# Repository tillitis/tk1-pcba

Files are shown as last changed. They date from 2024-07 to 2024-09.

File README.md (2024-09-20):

# TK1 PCBA

This repository contains the PCB design and manufacturing files for
the flexible Open Source security key, TKey (TK1).

This is part of a larger project that includes firmware and FPGA
designs, which are housed at
[tillitis-key1](https://github.com/tillitis/tillitis-key1).

For more general information about the TKey see,
- [www.tillitis.se](https://tillitis.se)
- [shop.tillitis.se](https://shop.tillitis.se)
- [TKey Developer Handbook](https://dev.tillitis.se/)

## Repository Contents
- KiCad project files for
    - tk1, under hw
    - mta1-usb-v1, under prototypes
    - mta1-usb-dev, under prototypes
- Manufacturing outputs (Gerber files, BOM, etc.), under [Github
  releases](https://github.com/tillitis/tk1-pcba/releases)
- Libraries, under hw/lib

The earlier version of TK1, such as the `mta1-usb-v1` and
`mta1-usb-dev`, that can be found under `prototypes/` are kept for
historical reasons. TK1 is the only version that is maintained and
developed.

## Getting started
1. Clone this repository:
2. Open the project file (`hw/tk1.kicad_pro`) in KiCad.

alternatively download a release to get the generated output (Gerber,
schematics etc.) to be viewed in your preferred tool.

## KiCad and tools
The project is built using KiCad version 7. Production files are built
in CI using KiBot, see the Makefile for exact version.

The KiBot flow can be run locally using the Make target

```
make run-kibot
```

the prerequisites are `Podman`. `Docker` can also be used, see the
Makefile for details.

## License
Unless otherwise noted, this project is licensed under CERN Open
Hardware License Version 2 - Strongly Reciprocal, see full license
under [LICENSE.txt](/LICENSE.txt).
```
Copyright Tillitis AB 2022-2024.

This source describes Open Hardware and is licensed under the CERN-OHL-S v2.

You may redistribute and modify this source and make products using it under
the terms of the CERN-OHL-S v2 (https://ohwr.org/cern_ohl_s_v2.txt).

This source is distributed WITHOUT ANY EXPRESS OR IMPLIED WARRANTY,
INCLUDING OF MERCHANTABILITY, SATISFACTORY QUALITY AND FITNESS FOR A
PARTICULAR PURPOSE. Please see the CERN-OHL-S v2 for applicable conditions.

Source location: https://github.com/tillitis/tk1-pcba

As per CERN-OHL-S v2 section 4, should You produce hardware based on this
source, You must where practicable maintain the Source Location visible
on the external case of the product or its packaging, and in its
documentation, even after modification.
```

The [CERN-OHL-S user guide](/User-guide-CERN-OHL-S.txt) is included to
make it easier to follow the license, both as a Licensor or a Licensee.

## History
This repo was created by filtering out relevant commits and files from
the [tillitis/tillits-key1](https://github.com/tillitis/tillitis-key1)
repo.

The filtering removed all files and commits that weren't related to
the tk1 hardware. This was done using
[git-filter-repo](https://github.com/newren/git-filter-repo).

To replicate the results up until commit `6c7629c` in this repo,
checkout commit `354aecb` in `tillitis/tillitis-key1` and run
`git-filter-repo --path hw/boards/mta1-library --path
hw/boards/mta1-usb-dev --path hw/boards/mta1-usb-v1 --path
hw/boards/tk1`.

All filtered commits have intact date, author, and code. Some
unrelated files are removed from some commits, but the commit messages
are left unchanged. Commit sha, tags and signatures are new. For
complete history, please see tillitis/tillitis-key1 from commit
`354aecb` and earlier.

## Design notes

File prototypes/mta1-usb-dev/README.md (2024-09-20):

# mta1-usb-dev

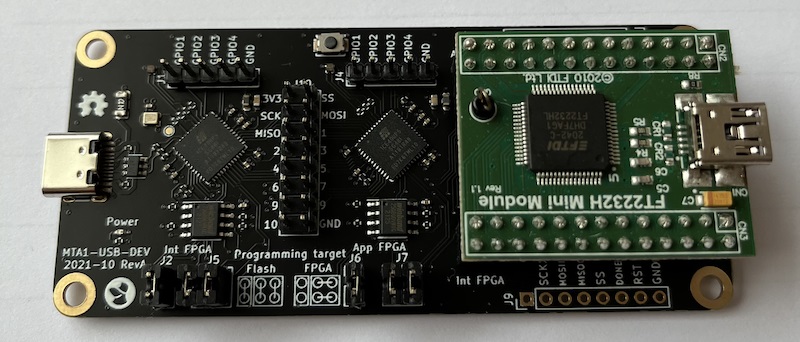
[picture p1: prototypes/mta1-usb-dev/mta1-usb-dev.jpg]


This is the original TKey design, intended as a development platform.
It is a larger PCB, that connects to a PC via a USB C cable.

Main features:
- 2 ICE40 FPGAs.

- The first ICE40 (Interface FPGA) is connected to a USB C plug, and
is loaded with a gateware that contains a soft USB device. This
gateware acts as an USB-to-GPIO interface to the second ICE40.

- The second ICE40 (application FPGA) is loaded with a RISC-V soft
core containing the security firmware. User applications are run on
this gateware.

- The second ICE40 also has an input button for user presenence
detection.

- An FTDI module is included for programming both the Application and
Interface FPGAs.

- Both ICE40s can be configured to boot from included SPI flash
memories, NVCM, or be live programmed from the FTDI module.

- All GPIO lines between the two FPGAs, as well as all programming
signals, are exposed on 0.1" headers for probing.

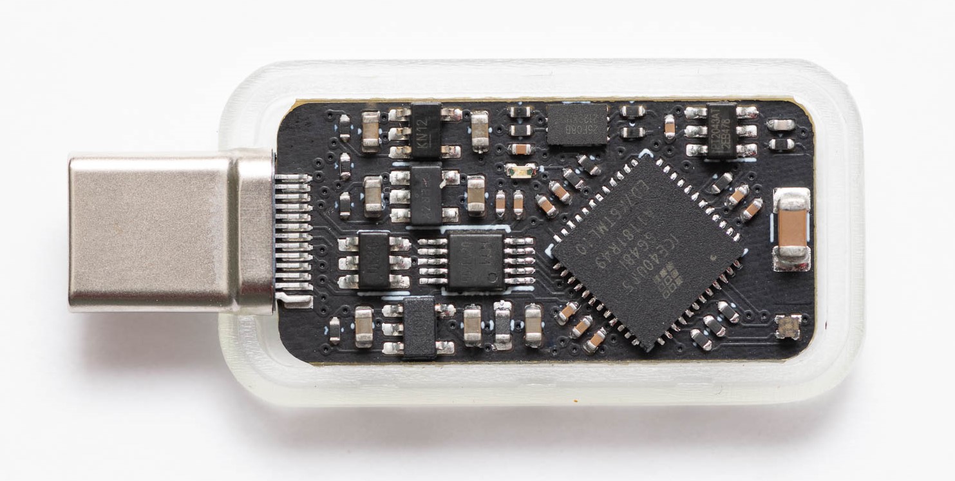
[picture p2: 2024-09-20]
prototypes/mta1-usb-v1/mta1-usb-v1.jpg

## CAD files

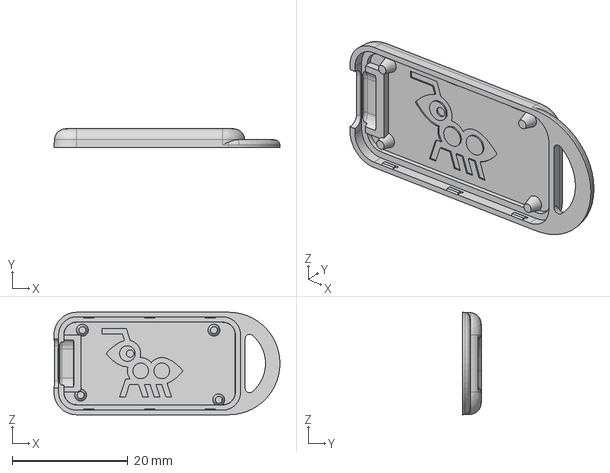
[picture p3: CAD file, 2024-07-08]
hw/case_plastic/3D_printed/case_top_revc.step
39.0 x 3.20 x 17.7 mm

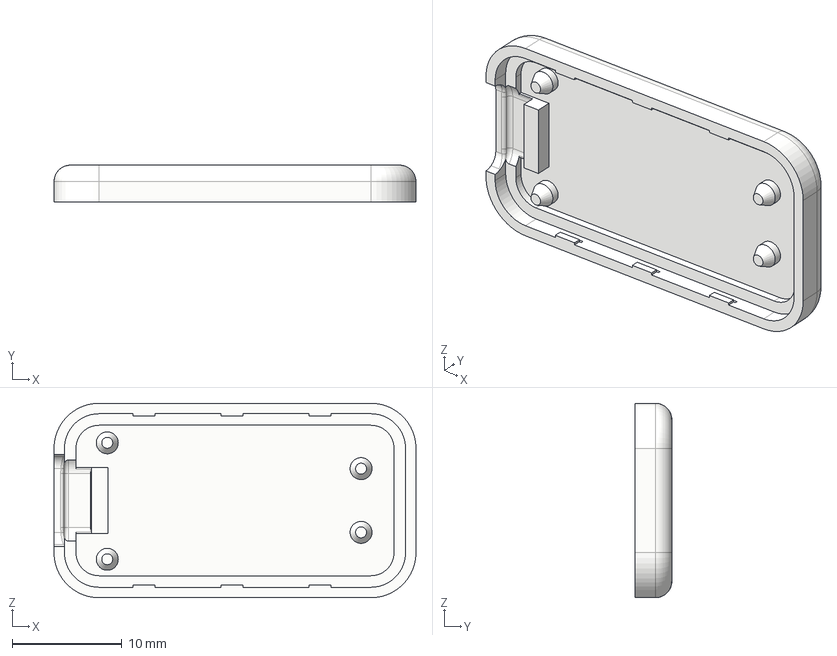
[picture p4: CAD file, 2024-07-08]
prototypes/mta1-usb-v1/case_plastic/2022-08-22 case production top.step
33.0 x 3.35 x 17.7 mm

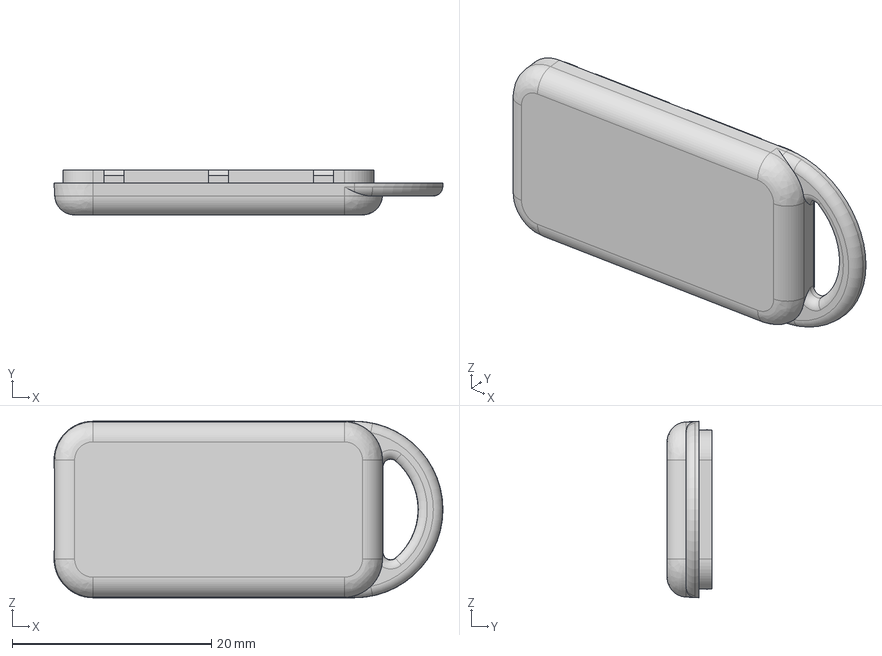
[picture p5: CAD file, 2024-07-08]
hw/case_plastic/3D_printed/case_bottom_revc.step
39.0 x 4.50 x 17.7 mm

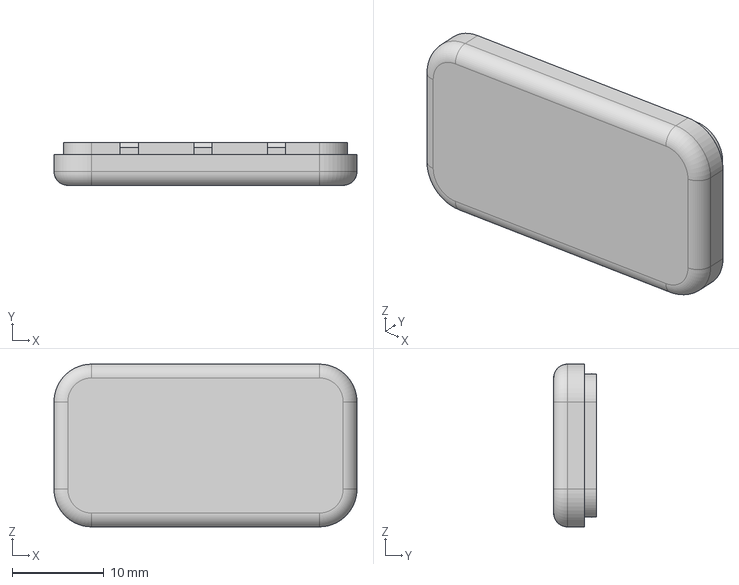
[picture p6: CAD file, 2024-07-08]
prototypes/mta1-usb-v1/case_plastic/2022-08-22 case production bottom.step
33.0 x 4.65 x 17.7 mm

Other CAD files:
prototypes/mta1-usb-v1/case_plastic/2022-08-22 case v3.f3z

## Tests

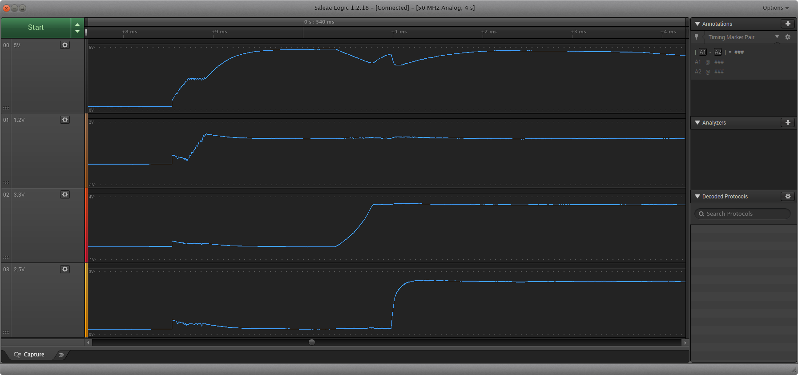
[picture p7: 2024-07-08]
prototypes/mta1-usb-dev/test/voltage_rails_test.png

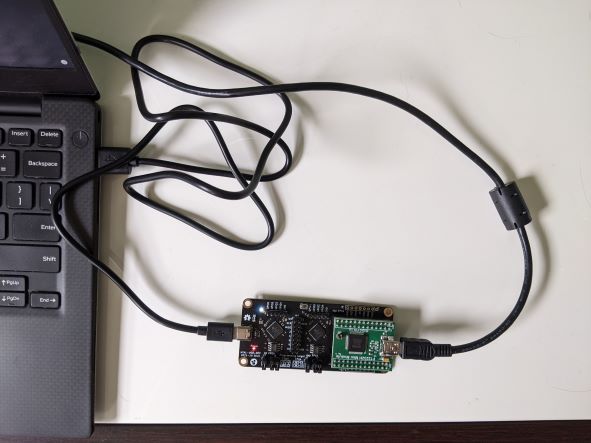
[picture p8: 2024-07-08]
prototypes/mta1-usb-dev/test/usb_test_setup.jpg

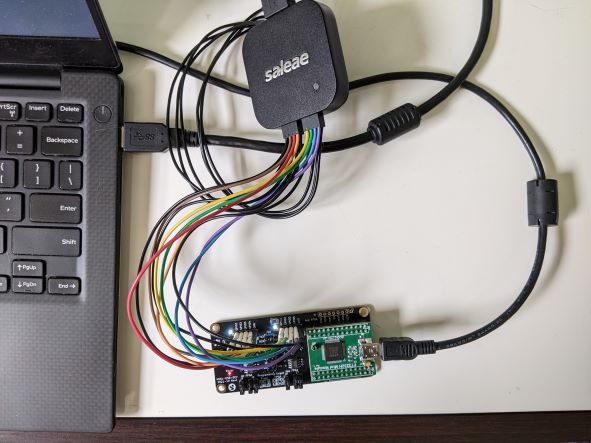
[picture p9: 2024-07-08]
prototypes/mta1-usb-dev/test/gpio_test_setup.jpg

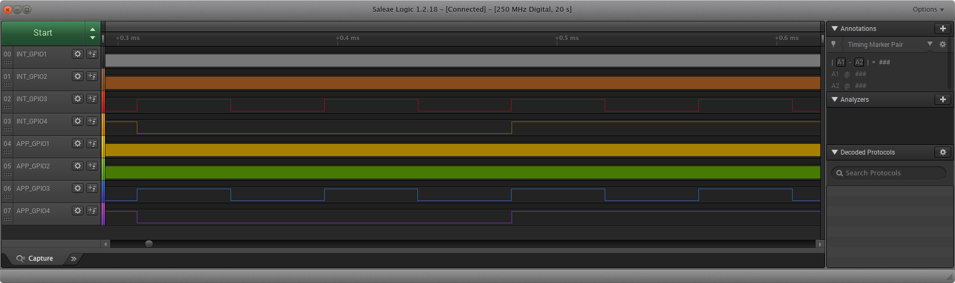
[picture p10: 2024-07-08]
prototypes/mta1-usb-dev/test/gpio_test.png

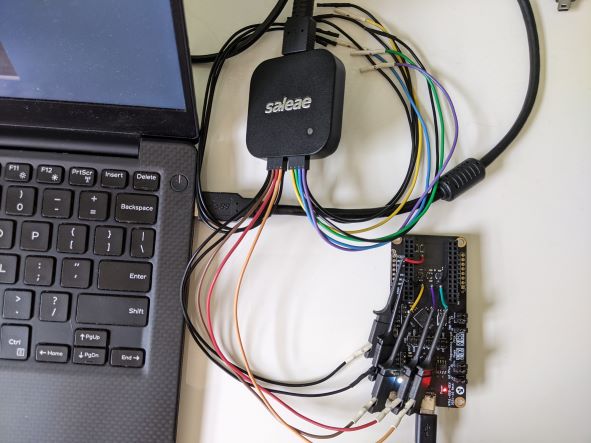
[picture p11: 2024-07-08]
prototypes/mta1-usb-dev/test/voltage_rail_test_setup.jpg

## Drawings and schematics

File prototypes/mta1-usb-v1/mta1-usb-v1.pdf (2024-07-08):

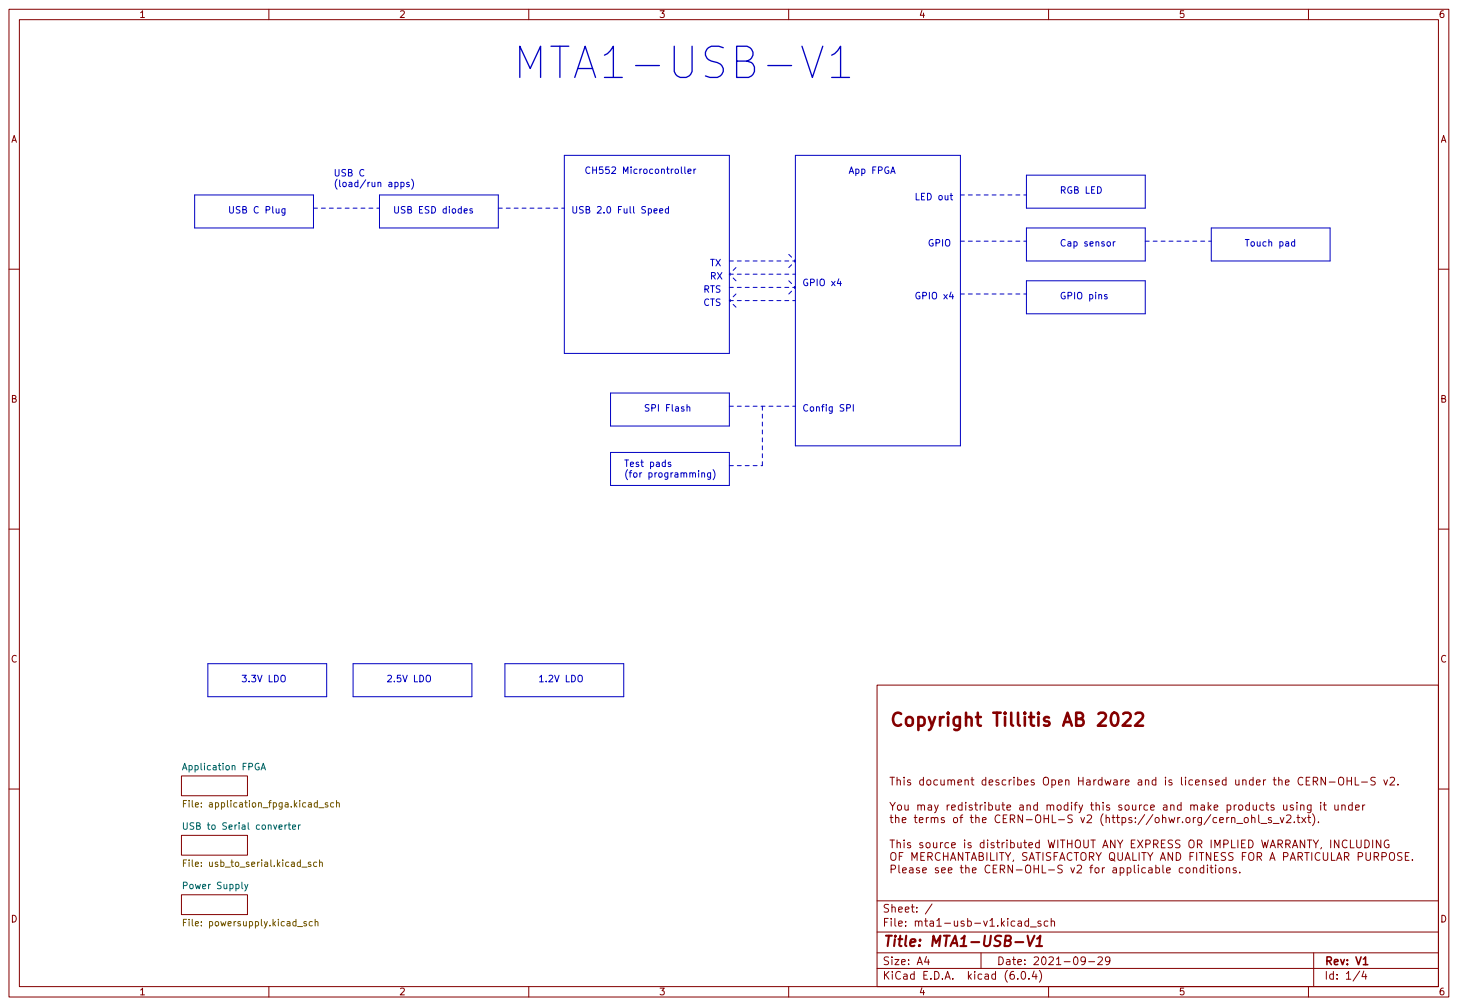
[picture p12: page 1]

Cap sensor USB ESD diodes USB C
(load/run apps)

File: application_fpga.kicad_sch USB to Serial converter File: usb_to_serial.kicad_sch Power Supply

File: mta1-usb-v1.kicad_sch Sheet: / This document describes Open Hardware and is licensed under the CERN-OHL-S v2.

You may redistribute and modify this source and make products using it under

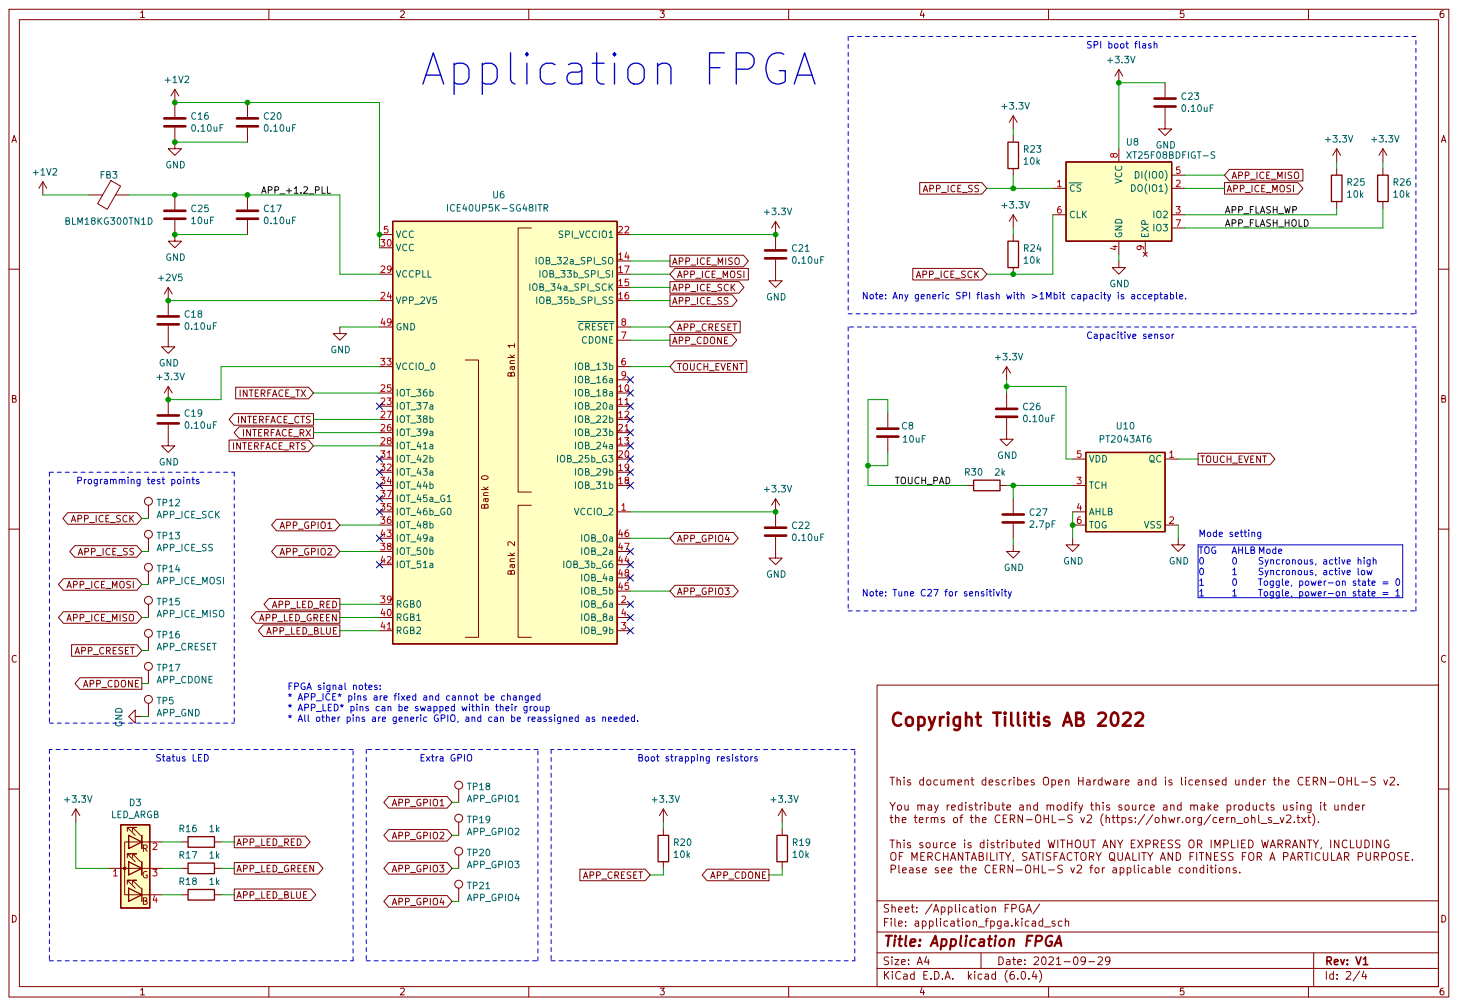
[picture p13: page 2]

1 Note: Any generic SPI flash with >1Mbit capacity is acceptable. SPI boot flash

Toggle, power-on state = 1 AHLB
Syncronous, active low
Toggle, power-on state = 0

Note: Tune C27 for sensitivity

FPGA signal notes:
* APP_ICE* pins are fixed and cannot be changed
* APP_LED* pins can be swapped within their group
* All other pins are generic GPIO, and can be reassigned as needed.

This document describes Open Hardware and is licensed under the CERN-OHL-S v2.

You may redistribute and modify this source and make products using it under

Sheet: /Application FPGA/
File: application_fpga.kicad_sch
Id: 2/4 Title: Application FPGA

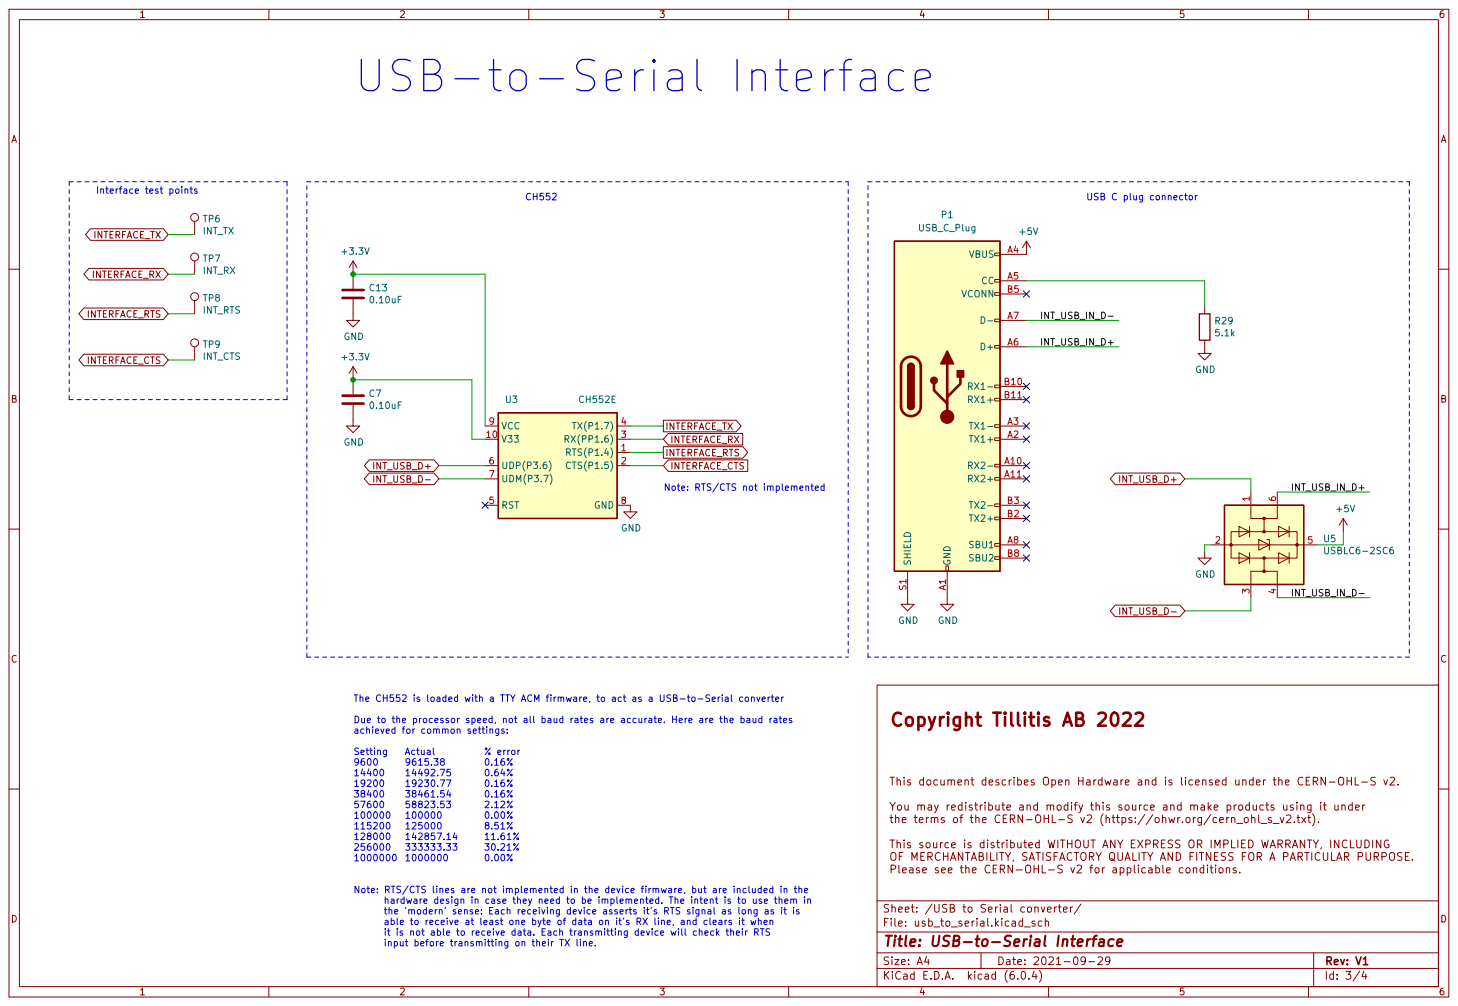
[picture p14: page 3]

USB-to-Serial Interface

INT_USB_IN_D- The CH552 is loaded with a TTY ACM firmware, to act as a USB-to-Serial converter Due to the processor speed, not all baud rates are accurate. Here are the baud rates

achieved for common settings:

File: usb_to_serial.kicad_sch Sheet: /USB to Serial converter/ This document describes Open Hardware and is licensed under the CERN-OHL-S v2.

You may redistribute and modify this source and make products using it under

Note: RTS/CTS lines are not implemented in the device firmware, but are included in the
hardware design in case they need to be implemented. The intent is to use them in
the 'modern' sense: Each receiving device asserts it's RTS signal as long as it is
able to receive at least one byte of data on it's RX line, and clears it when
it is not able to receive data. Each transmitting device will check their RTS
input before transmitting on their TX line.

Id: 3/4 Title: USB-to-Serial Interface

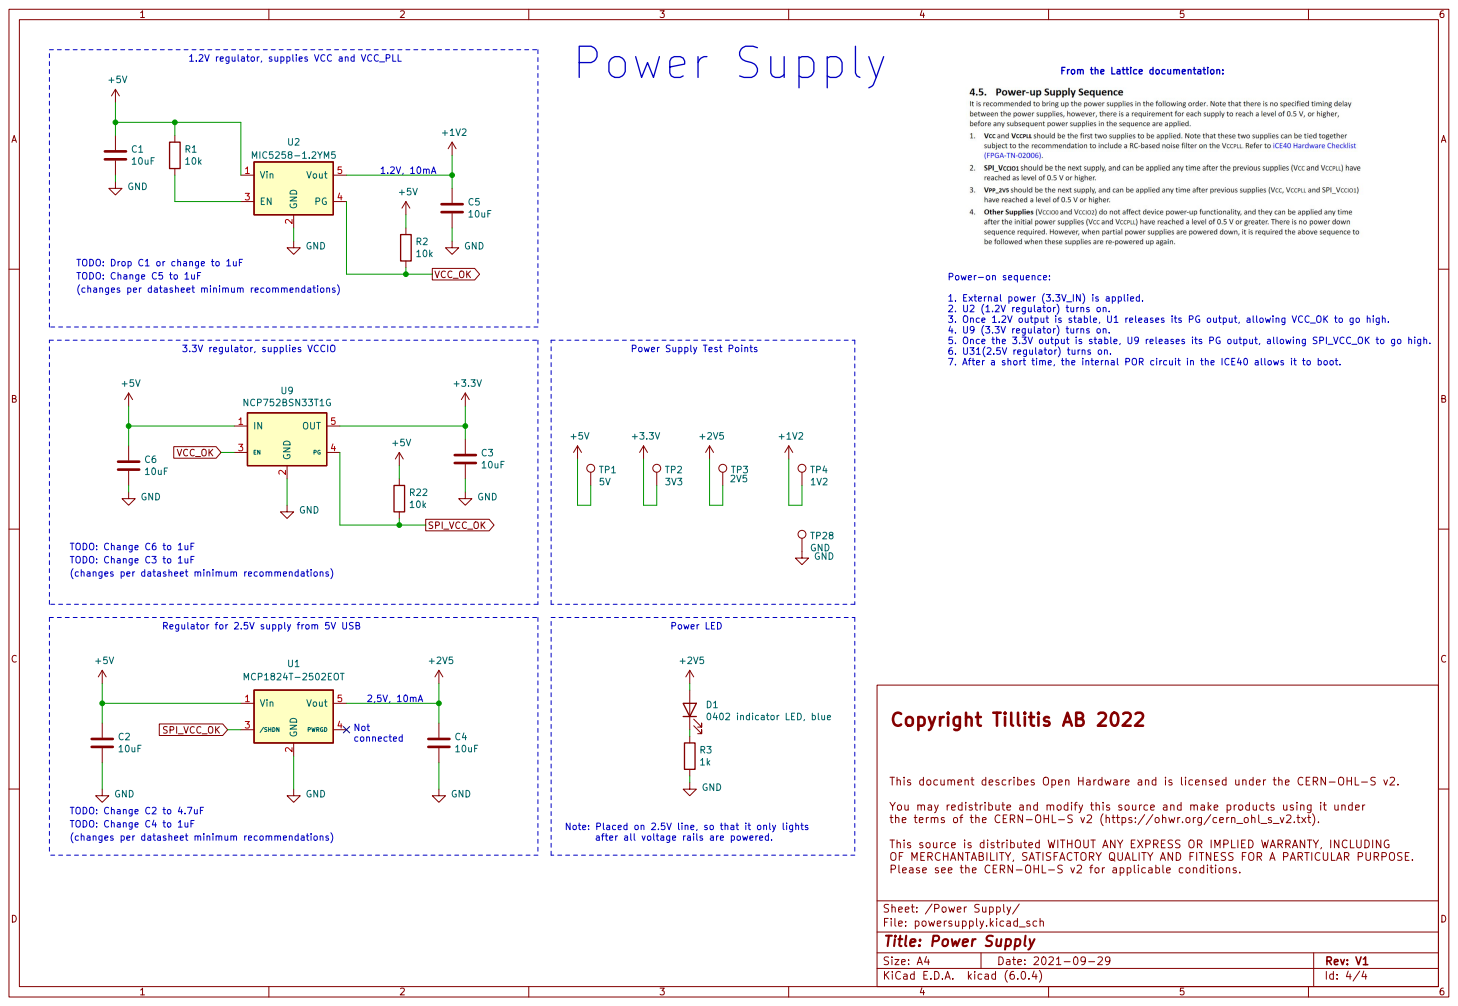
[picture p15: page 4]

1.2V regulator, supplies VCC and VCC_PLL

TODO: Drop C1 or change to 1uF
TODO: Change C5 to 1uF
(changes per datasheet minimum recommendations)

1. External power (3.3V_IN) is applied.
2. U2 (1.2V regulator) turns on.
3. Once 1.2V output is stable, U1 releases its PG output, allowing VCC_OK to go high.
4. U9 (3.3V regulator) turns on.
5. Once the 3.3V output is stable, U9 releases its PG output, allowing SPI_VCC_OK to go high.

TODO: Change C6 to 1uF
TODO: Change C3 to 1uF

2,5V, 10mA Regulator for 2.5V supply from 5V USB

TODO: Change C2 to 4.7uF
TODO: Change C4 to 1uF

Note: Placed on 2.5V line, so that it only lights
after all voltage rails are powered.

This document describes Open Hardware and is licensed under the CERN-OHL-S v2.

You may redistribute and modify this source and make products using it under

Sheet: /Power Supply/
File: powersupply.kicad_sch
Id: 4/4 Title: Power Supply

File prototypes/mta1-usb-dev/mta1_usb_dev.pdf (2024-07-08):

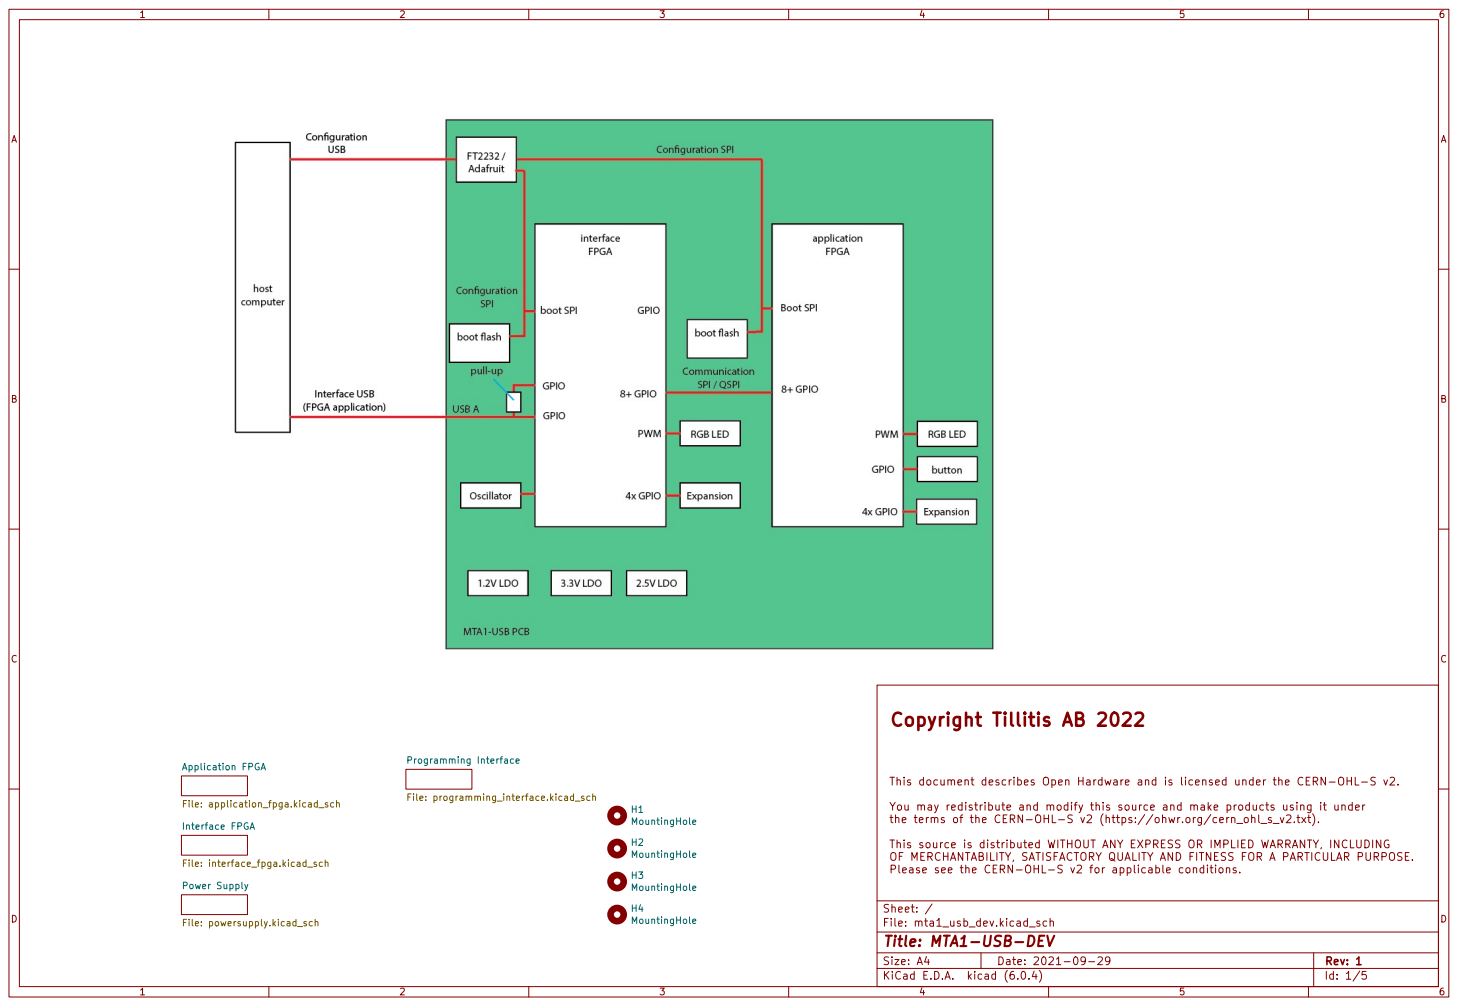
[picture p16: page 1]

File: mta1_usb_dev.kicad_sch Sheet: / This document describes Open Hardware and is licensed under the CERN-OHL-S v2.

You may redistribute and modify this source and make products using it under

Id: 1/5 Title: MTA1-USB-DEV

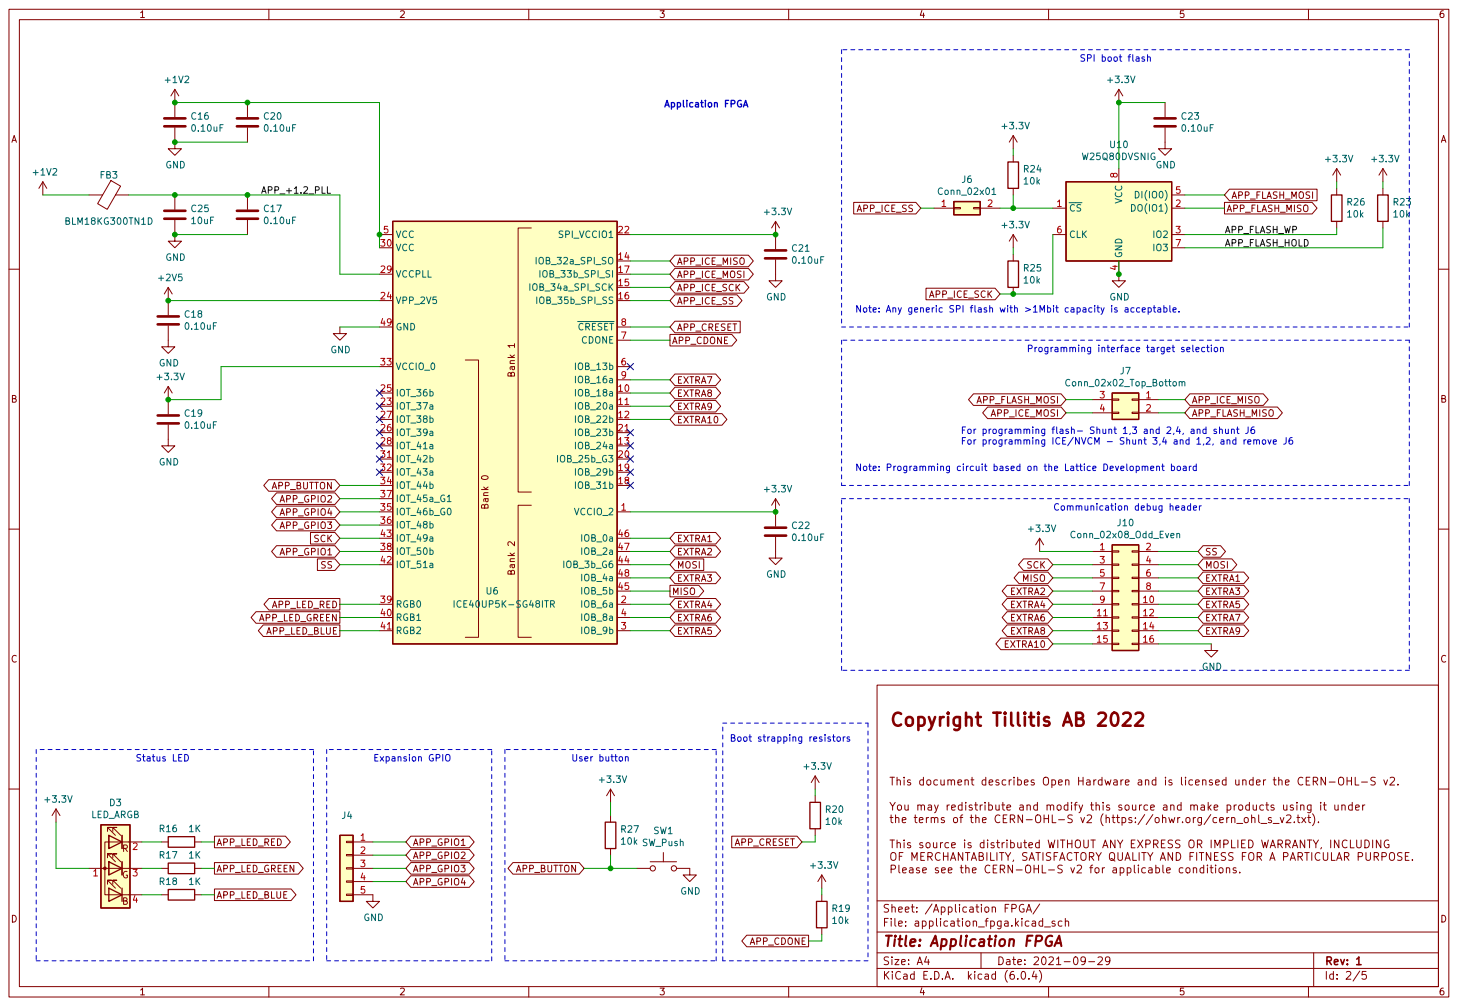
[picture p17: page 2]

Programming interface target selection SPI boot flash Application FPGA

Note: Any generic SPI flash with >1Mbit capacity is acceptable.

For programming ICE/NVCM - Shunt 3,4 and 1,2, and remove J6

Note: Programming circuit based on the Lattice Development board

Boot strapping resistors Status LED

This document describes Open Hardware and is licensed under the CERN-OHL-S v2.

You may redistribute and modify this source and make products using it under

Sheet: /Application FPGA/
File: application_fpga.kicad_sch
Id: 2/5 Title: Application FPGA

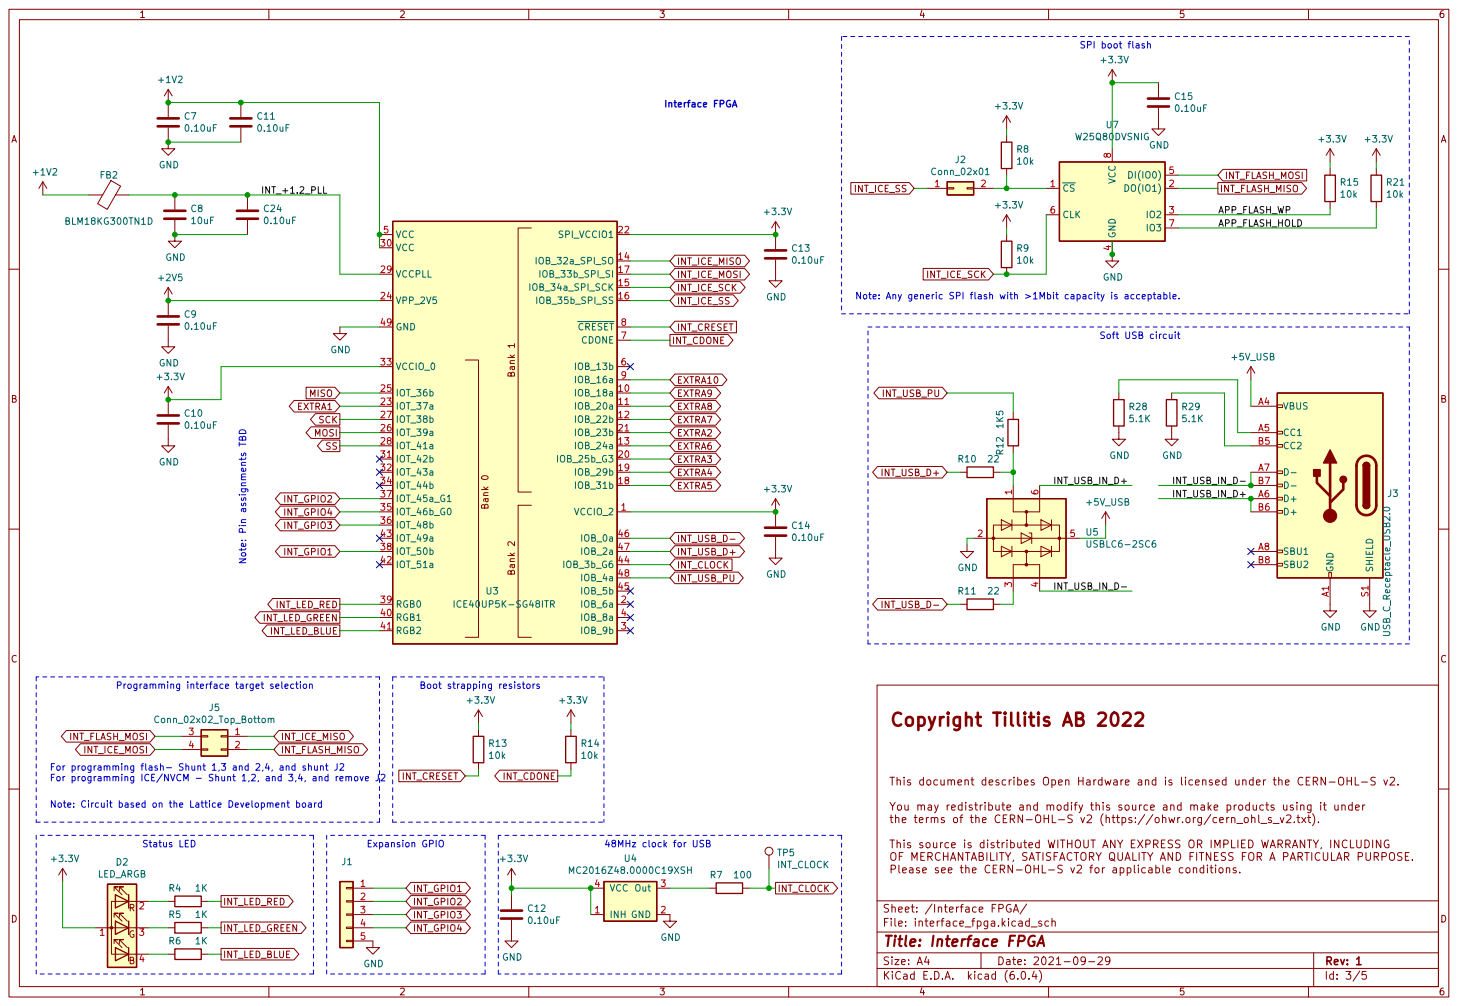
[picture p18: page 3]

Note: Any generic SPI flash with >1Mbit capacity is acceptable.

Programming interface target selection

For programming flash- Shunt 1,3 and 2,4, and shunt J2
For programming ICE/NVCM - Shunt 1,2, and 3,4, and remove J2

File: interface_fpga.kicad_sch Sheet: /Interface FPGA/ This document describes Open Hardware and is licensed under the CERN-OHL-S v2.

You may redistribute and modify this source and make products using it under

Id: 3/5 Title: Interface FPGA

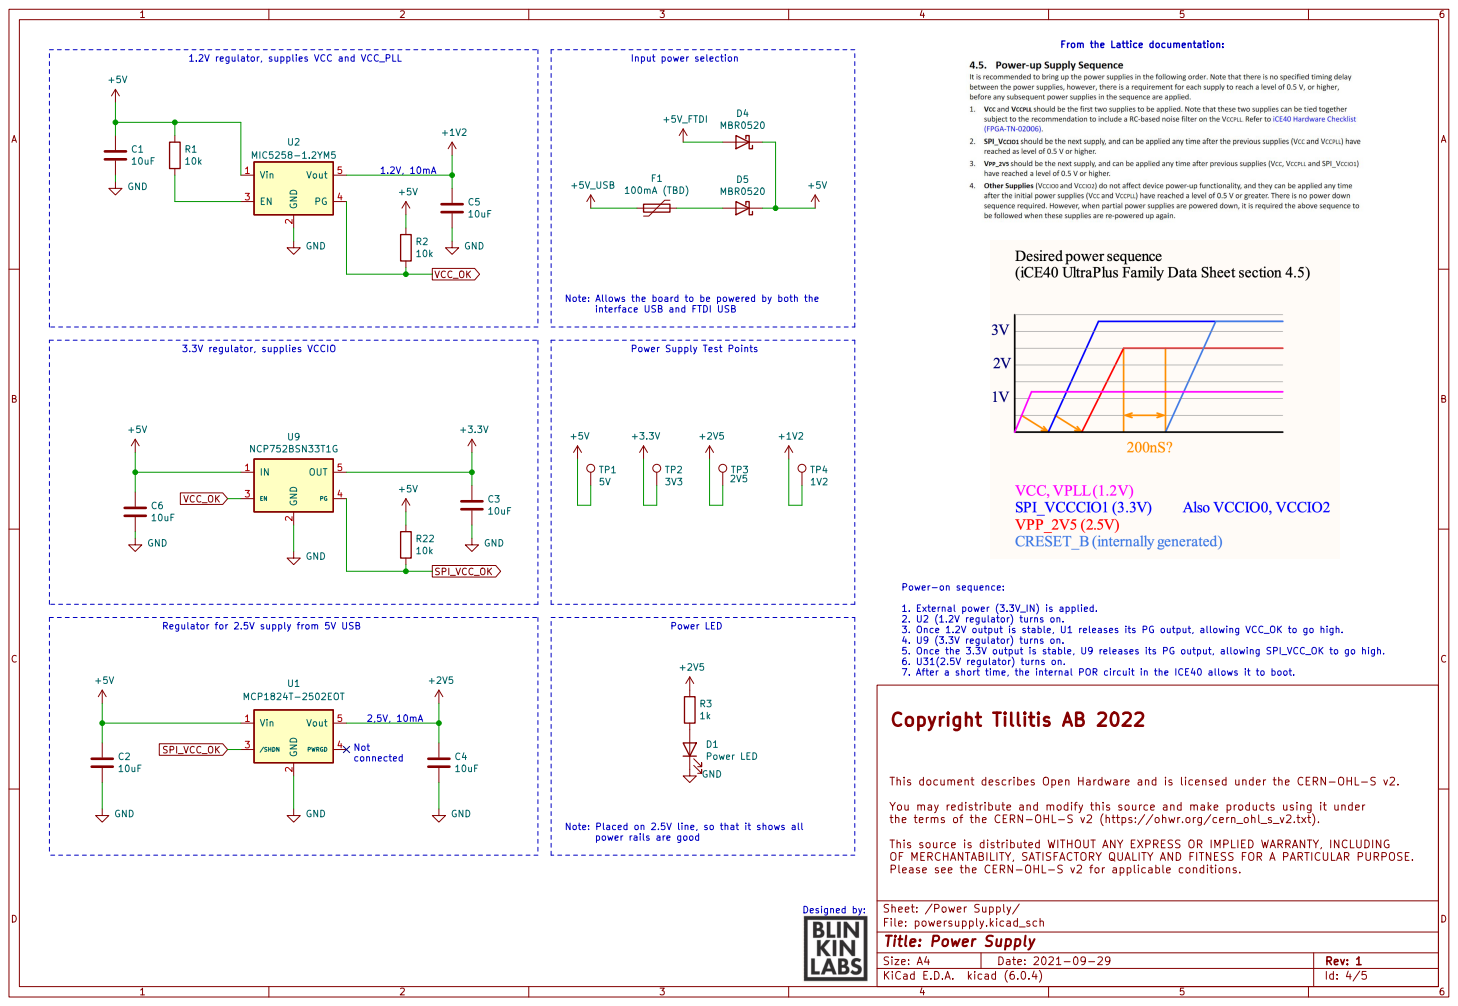
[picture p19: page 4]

From the Lattice documentation:
interface USB and FTDI USB Note: Placed on 2.5V line, so that it shows all power rails are good

2 EN 3 PG 4 Vout 5 U2 MIC5258-1.2YM5 GND GND
1.2V, 10mA Regulator for 2.5V supply from 5V USB
100mA (TBD) GND GND

Note: Allows the board to be powered by both the

Power Supply Test Points Not connected

1. External power (3.3V_IN) is applied.
2. U2 (1.2V regulator) turns on.
3. Once 1.2V output is stable, U1 releases its PG output, allowing VCC_OK to go high.
4. U9 (3.3V regulator) turns on.
5. Once the 3.3V output is stable, U9 releases its PG output, allowing SPI_VCC_OK to go high.
6. U31(2.5V regulator) turns on. 7. After a short time, the internal POR circuit in the ICE40 allows it to boot.

This document describes Open Hardware and is licensed under the CERN-OHL-S v2.

You may redistribute and modify this source and make products using it under

Sheet: /Power Supply/
File: powersupply.kicad_sch
Id: 4/5 Title: Power Supply

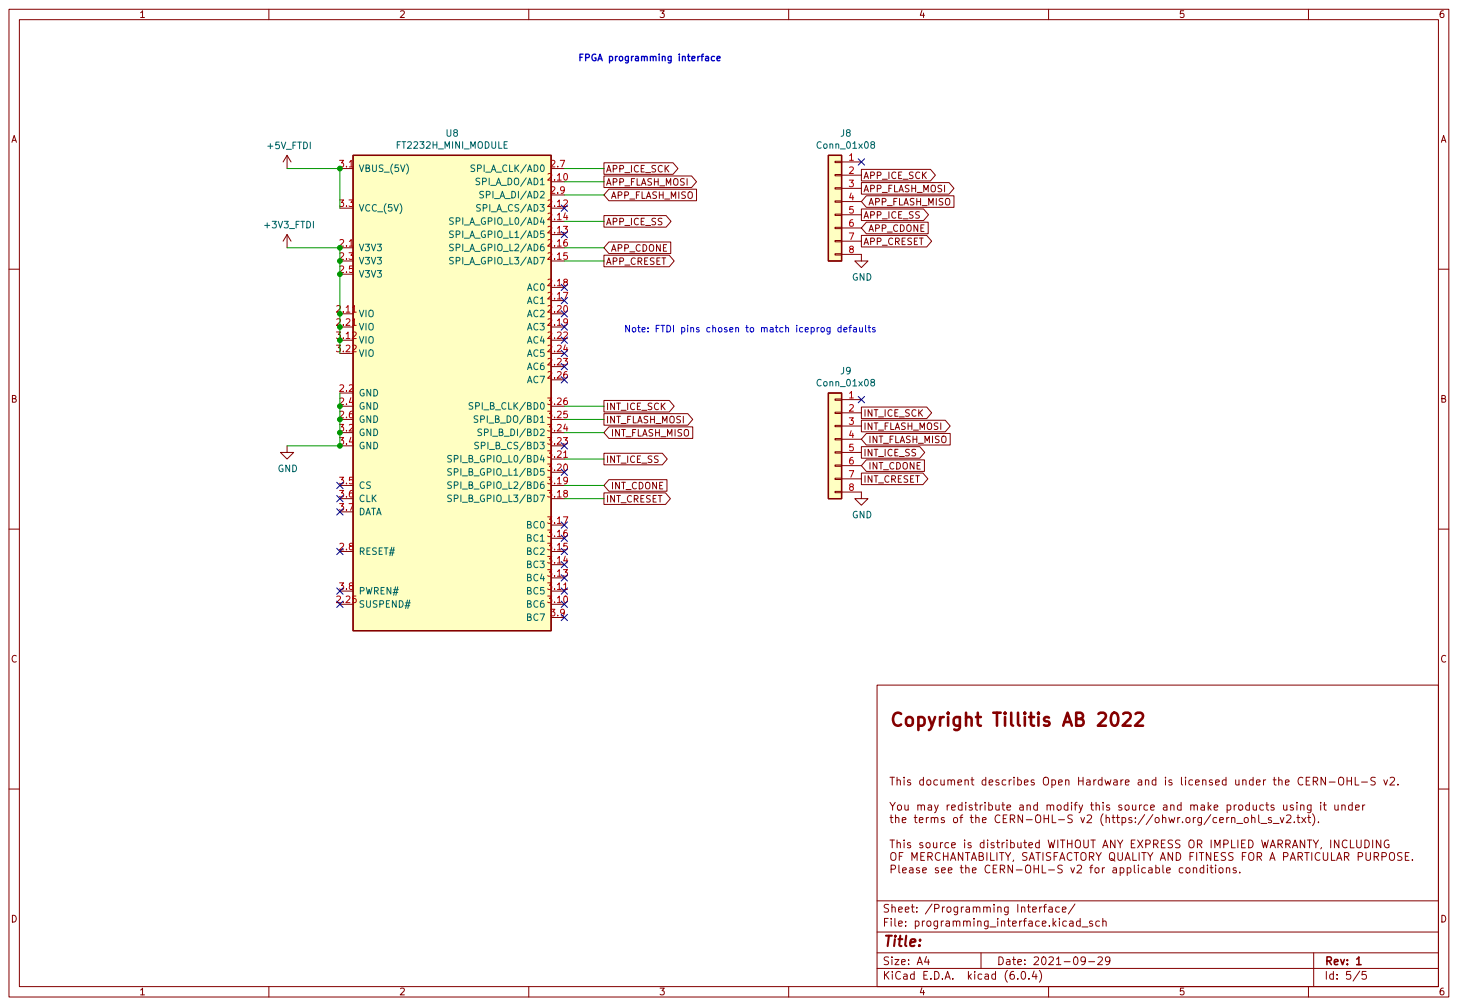
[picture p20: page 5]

APP_ICE_SS
APP_CRESET Note: FTDI pins chosen to match iceprog defaults
APP_CDONE

This document describes Open Hardware and is licensed under the CERN-OHL-S v2.

You may redistribute and modify this source and make products using it under

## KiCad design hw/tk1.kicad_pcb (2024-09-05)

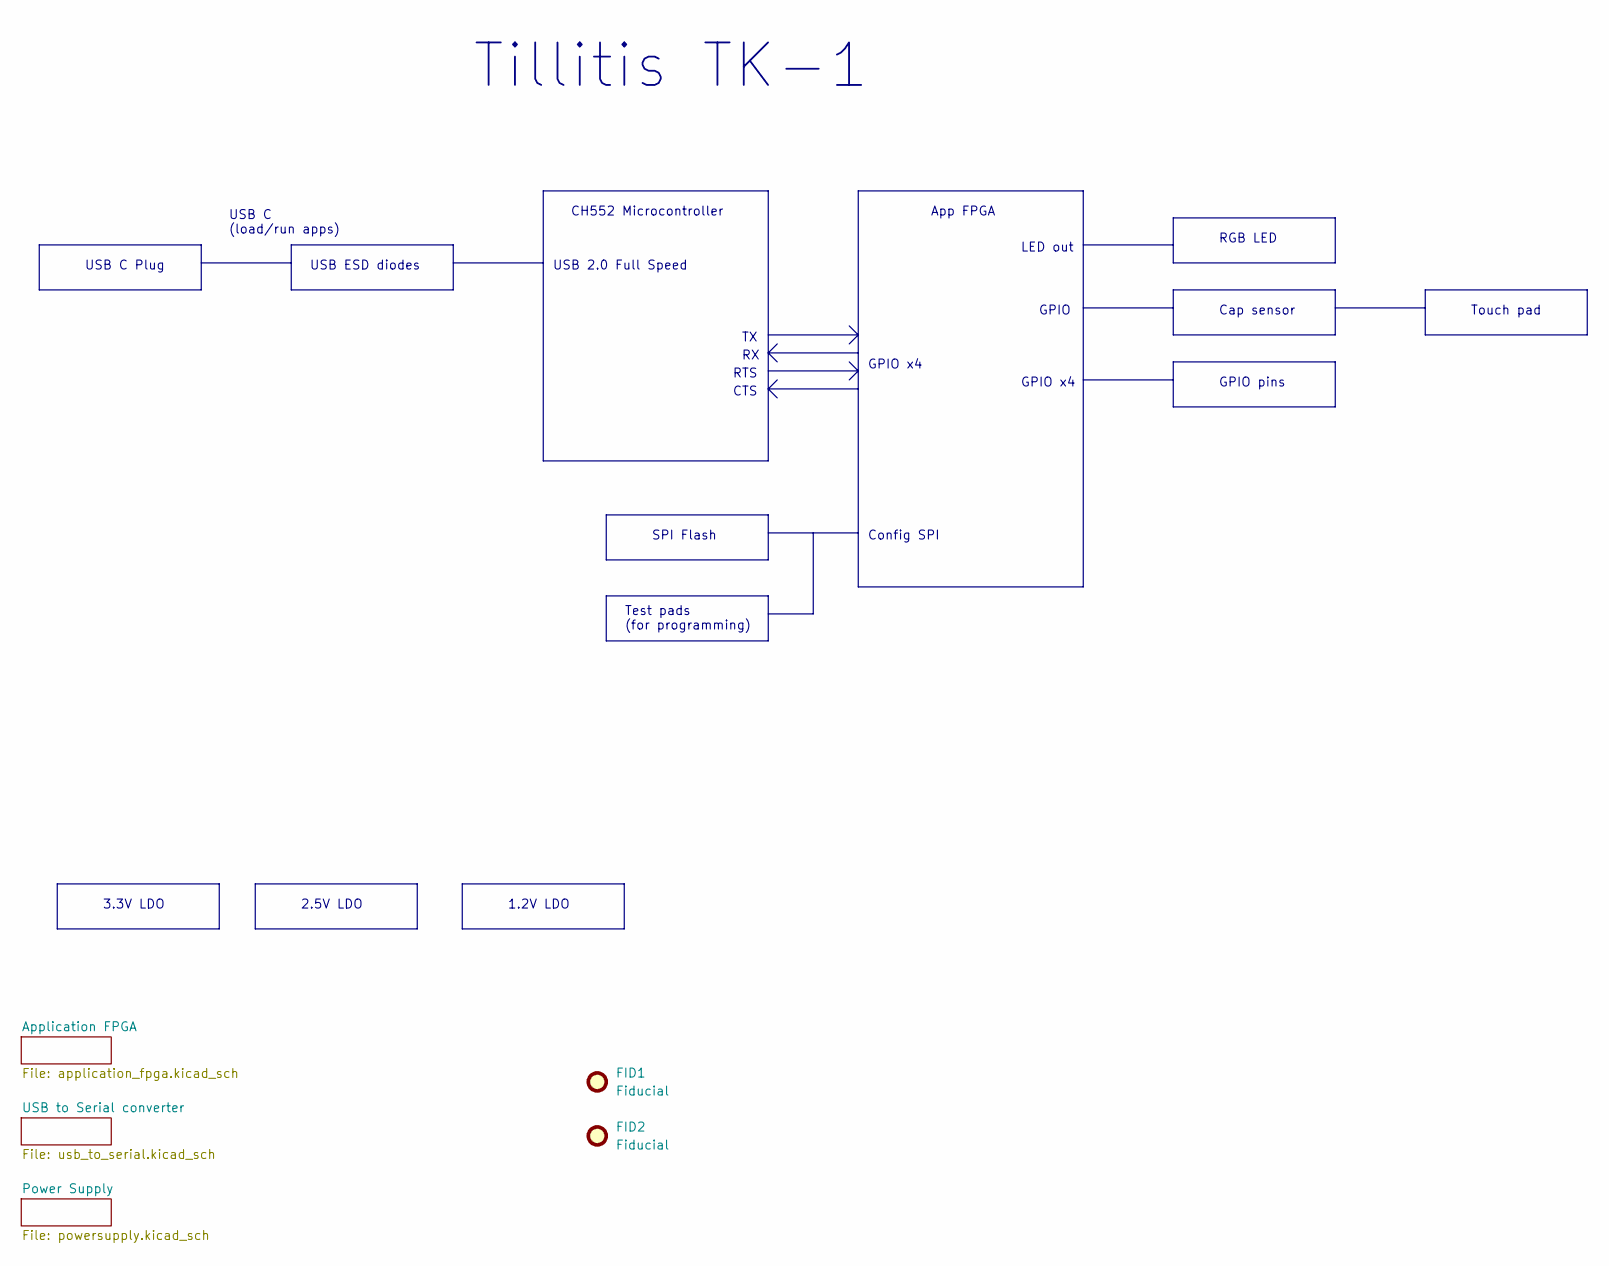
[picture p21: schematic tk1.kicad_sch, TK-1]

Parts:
FID1, FID2: Fiducial; Fiducial_0.75mm_Mask1.5mm

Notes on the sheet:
USB ESD diodes
Touch pad
GPIO x4
GPIO pins
Cap sensor
USB 2.0 Full Speed
RTS
USB C Plug
CH552 Microcontroller
RGB LED
USB C (load/run apps)
1.2V LDO
3.3V LDO
CTS
2.5V LDO
App FPGA
Config SPI
Tillitis TK-1
SPI Flash
GPIO
LED out
Test pads (for programming)

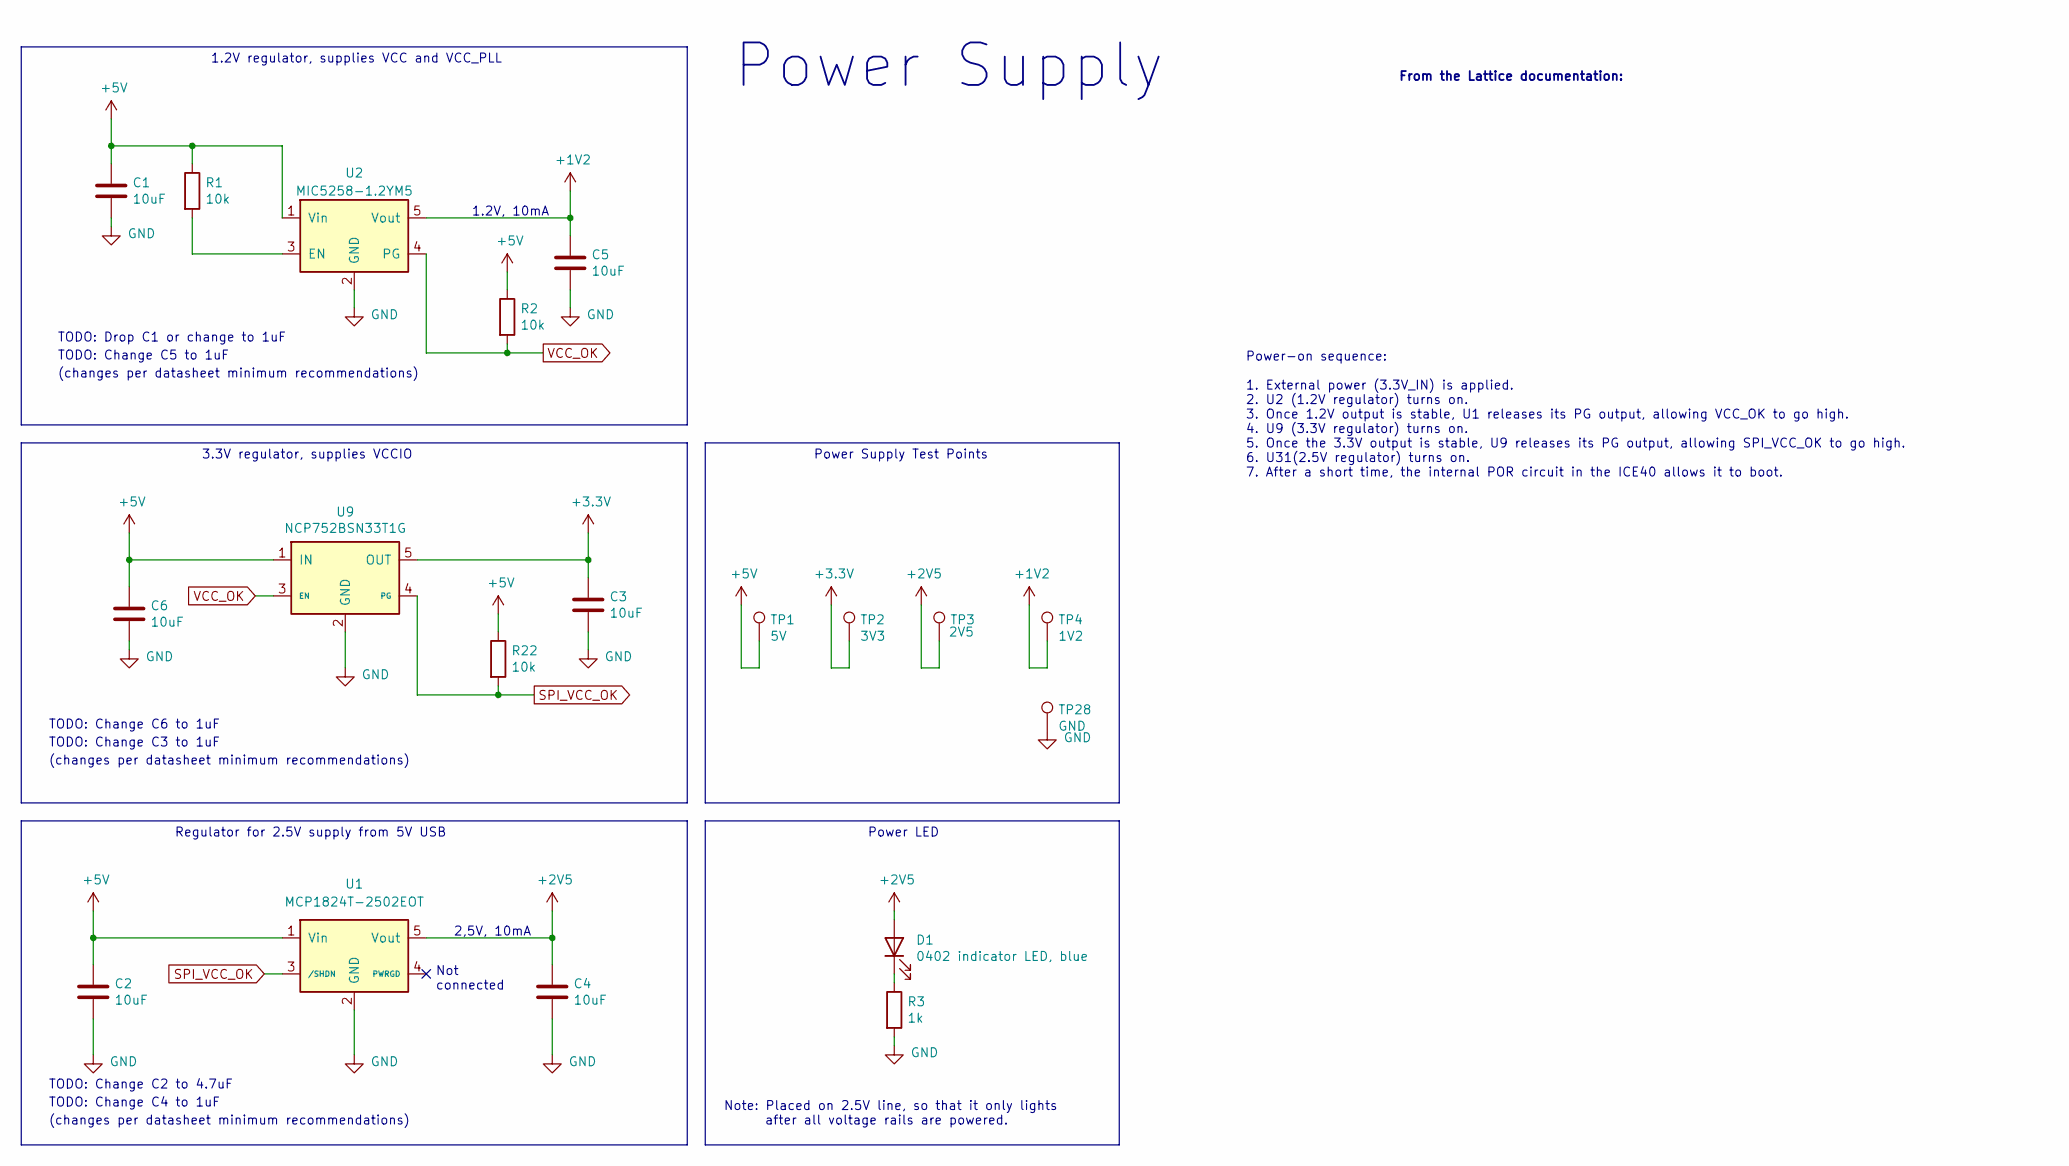
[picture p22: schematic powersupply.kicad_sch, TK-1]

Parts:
C1, C2, C3, C4, C5, C6: 10uF; CAPC1608X09L
D1: 0402 indicator LED, blue; LED_0402_1005Metric; Manufacturer Part Number NCD0402B1
R1, R2, R22: 10k; ERJ2G(0402)_L
R3: 1k; ERJ2G(0402)_L
TP1: 5V; TestPoint_Pad_D1.0mm
TP2: 3V3; TestPoint_Pad_D1.0mm
TP3: 2V5; TestPoint_Pad_D1.0mm
TP4: 1V2; TestPoint_Pad_D1.0mm
TP28: GND; TestPoint_Pad_D1.0mm
U1: MCP1824T-2502EOT; SOT-23-5; Manufacturer Part Number MCP1824T-2502EOT
U2: MIC5258-1.2YM5; SOT-23-5; Manufacturer Part Number MIC5258-1.2YM5
U9: NCP752BSN33T1G; Manufacturer Part Number NCP752BSN33T1G

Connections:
+1V2: C5.1, TP4.1, U2.5 (Vout); also elsewhere on the board
+2V5: C4.1, D1.2 (A), TP3.1, U1.5 (Vout); also elsewhere on the board
+3V3: C3.1, TP2.1, U9.5 (OUT); also elsewhere on the board
+5V: C1.1, C2.1, C6.1, R1.1, R2.1, R22.1, TP1.1, U1.1 (Vin), U2.1 (Vin), U9.1 (IN); also elsewhere on the board
GND: C1.2, C2.2, C3.2, C4.2, C5.2, C6.2, R3.2, TP28.1, U1.2 (GND), U2.2 (GND), U9.2 (GND); also elsewhere on the board
unnamed: D1.1 (K), R3.1
unnamed: R1.2, U2.3 (EN)
SPI_VCC_OK: R22.2, U1.3 (/SHDN), U9.4 (PG)
VCC_OK: R2.2, U2.4 (PG), U9.3 (EN)

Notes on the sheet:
Power-on sequence: 1. External power (3.3V_IN) is applied. 2. U2 (1.2V regulator) turns on. 3. Once 1.2V output is stable, U1 releases its PG output, allowing VCC_OK to go high. 4. U9 (3.3V regulator) turns on. 5. Once the 3.3V output is stable, U9 releases its PG output, allowing SPI_VCC_OK to go 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
TODO: Change C2 to 4.7uF
(changes per datasheet minimum recommendations)
TODO: Change C6 to 1uF
2,5V, 10mA
Note: Placed on 2.5V line, so that it only lights after all voltage rails are powered.
TODO: Change C3 to 1uF
1.2V, 10mA
Power Supply
TODO: Drop C1 or change to 1uF
TODO: Change C5 to 1uF
From the Lattice documentation:
1.2V regulator, supplies VCC and VCC_PLL
3.3V regulator, supplies VCCIO
TODO: Change C4 to 1uF
Not connected
Power Supply Test Points
Power LED
Regulator for 2.5V supply from 5V USB

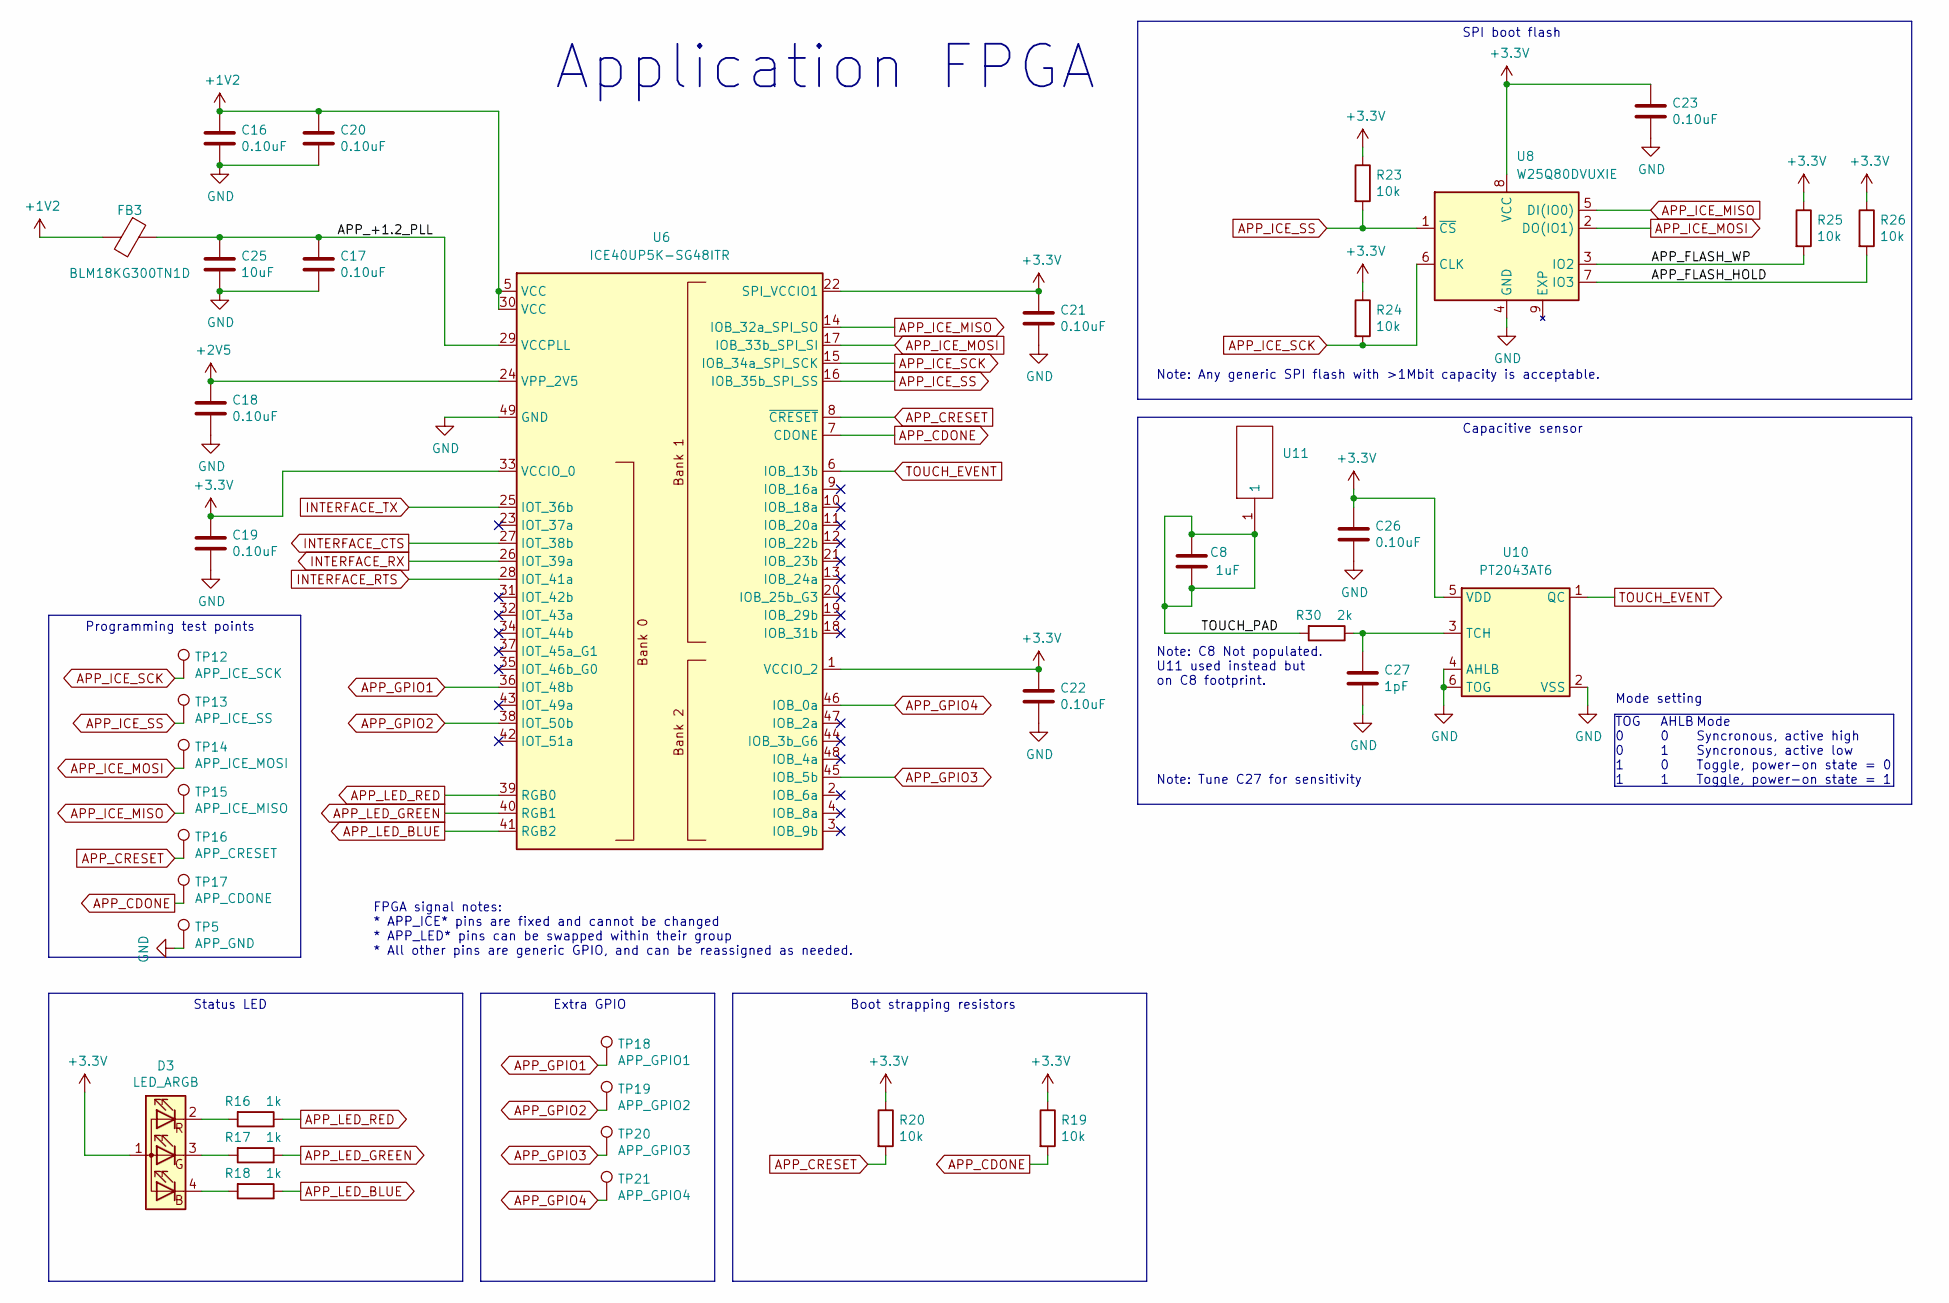
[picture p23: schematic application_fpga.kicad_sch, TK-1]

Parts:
C8: 1uF; C_1206_3216Metric; Manufacturer Part Number C3216X7R1H105K160AE
C16, C17, C18, C19, C20, C21, C22, C23, C26: 0.10uF; CAPC1005X06L
C25: 10uF; CAPC1608X09L
C27: 1pF; CAPC1005X06L
D3: LED_ARGB; 0402rgb-1010; Manufacturer Part Number FC-B1010RGBT-HG
FB3: BLM18KG300TN1D; Ferritbead_0603_1608Metric; Manufacturer Part Number BLM18KG300TN1D
R16, R17, R18: 1k; ERJ2G(0402)_L
R19, R20, R23, R24, R25, R26: 10k; ERJ2G(0402)_L
R30: 2k; ERJ2G(0402)_L
TP5: APP_GND; TestPoint_Pad_D1.0mm
TP12: APP_ICE_SCK; TestPoint_Pad_D1.0mm
TP13: APP_ICE_SS; TestPoint_Pad_D1.0mm
TP14: APP_ICE_MOSI; TestPoint_Pad_D1.0mm
TP15: APP_ICE_MISO; TestPoint_Pad_D1.0mm
TP16: APP_CRESET; TestPoint_Pad_D1.0mm
TP17: APP_CDONE; TestPoint_Pad_D1.0mm
TP18: APP_GPIO1; TestPoint_Pad_D1.0mm
TP19: APP_GPIO2; TestPoint_Pad_D1.0mm
TP20: APP_GPIO3; TestPoint_Pad_D1.0mm
TP21: APP_GPIO4; TestPoint_Pad_D1.0mm
U6: ICE40UP5K-SG48ITR; QFN-48-1EP_7x7mm_P0.5mm_EP5.6x5.6mm; Manufacturer Part Number ICE40UP5K-SG48ITR
U8: W25Q80DVUXIE; Manufacturer Part Number W25Q80DVUXIE
U10: PT2043AT6; SOT-23-6; Manufacturer Part Number PT2043AT6
U11: Mouser Part Number 571-1674954-1

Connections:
+1V2: C16.1, C20.1, FB3.2, U6.5 (VCC), U6.30 (VCC); also elsewhere on the board
+2V5: C18.1, U6.24 (VPP_2V5); also elsewhere on the board
+3V3: C19.1, C21.1, C22.1, C23.1, C26.1, D3.1 (A), R19.1, R20.1, R23.1, R24.1, R25.1, R26.1, U6.1 (VCCIO_2), U6.22 (SPI_VCCIO1), U6.33 (VCCIO_0), U8.8 (VCC), U10.5 (VDD); also elsewhere on the board
/Application FPGA/APP_+1.2_PLL: C17.1, C25.1, FB3.1, U6.29 (VCCPLL)
/Application FPGA/APP_FLASH_HOLD: R26.2, U8.7 (IO3)
/Application FPGA/APP_FLASH_WP: R25.2, U8.3 (IO2)
/Application FPGA/TOUCH_PAD: C8.1, C8.2, R30.2, U11.1
APP_CDONE: R19.2, TP17.1, U6.7 (CDONE)
APP_CRESET: R20.2, TP16.1, U6.8 (~CRESET)
APP_GPIO1: TP18.1, U6.36 (IOT_48b)
APP_GPIO2: TP19.1, U6.38 (IOT_50b)
APP_GPIO3: TP20.1, U6.45 (IOB_5b)
APP_GPIO4: TP21.1, U6.46 (IOB_0a)
APP_ICE_MISO: TP15.1, U6.14 (IOB_32a_SPI_SO), U8.5 (DI(IO0))
APP_ICE_MOSI: TP14.1, U6.17 (IOB_33b_SPI_SI), U8.2 (DO(IO1))
APP_ICE_SCK: R24.2, TP12.1, U6.15 (IOB_34a_SPI_SCK), U8.6 (CLK)
APP_ICE_SS: R23.2, TP13.1, U6.16 (IOB_35b_SPI_SS), U8.1 (~CS)
APP_LED_BLUE: R18.1, U6.41 (RGB2)
APP_LED_GREEN: R17.1, U6.40 (RGB1)
APP_LED_RED: R16.1, U6.39 (RGB0)
GND: C16.2, C17.2, C18.2, C19.2, C20.2, C21.2, C22.2, C23.2, C25.2, C26.2, C27.2, TP5.1, U6.49 (GND), U8.4 (GND), U10.2 (VSS), U10.4 (AHLB), U10.6 (TOG); also elsewhere on the board
INTERFACE_CTS: U6.27 (IOT_38b); also elsewhere on the board
INTERFACE_RTS: U6.28 (IOT_41a); also elsewhere on the board
INTERFACE_RX: U6.26 (IOT_39a); also elsewhere on the board
INTERFACE_TX: U6.25 (IOT_36b); also elsewhere on the board
unnamed: C27.1, R30.1, U10.3 (TCH)
unnamed: D3.2 (RK), R16.2
unnamed: D3.3 (GK), R17.2
unnamed: D3.4 (BK), R18.2
TOUCH_EVENT: U6.6 (IOB_13b), U10.1 (QC)

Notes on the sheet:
Application FPGA
Mode Syncronous, active high Syncronous, active low Toggle, power-on state = 0 Toggle, power-on state = 1
Capacitive sensor
SPI boot flash
FPGA signal notes: * APP_ICE* pins are fixed and cannot be changed * APP_LED* pins can be swapped within their group * All other pins are generic GPIO, and can be reassigned as needed.
Boot strapping resistors
AHLB 0 1 0 1
Status LED
Note: Tune C27 for sensitivity
Programming test points
Note: C8 Not populated. U11 used instead but on C8 footprint.
Mode setting
Note: Any generic SPI flash with >1Mbit capacity is acceptable.
Extra GPIO
TOG 0 0 1 1

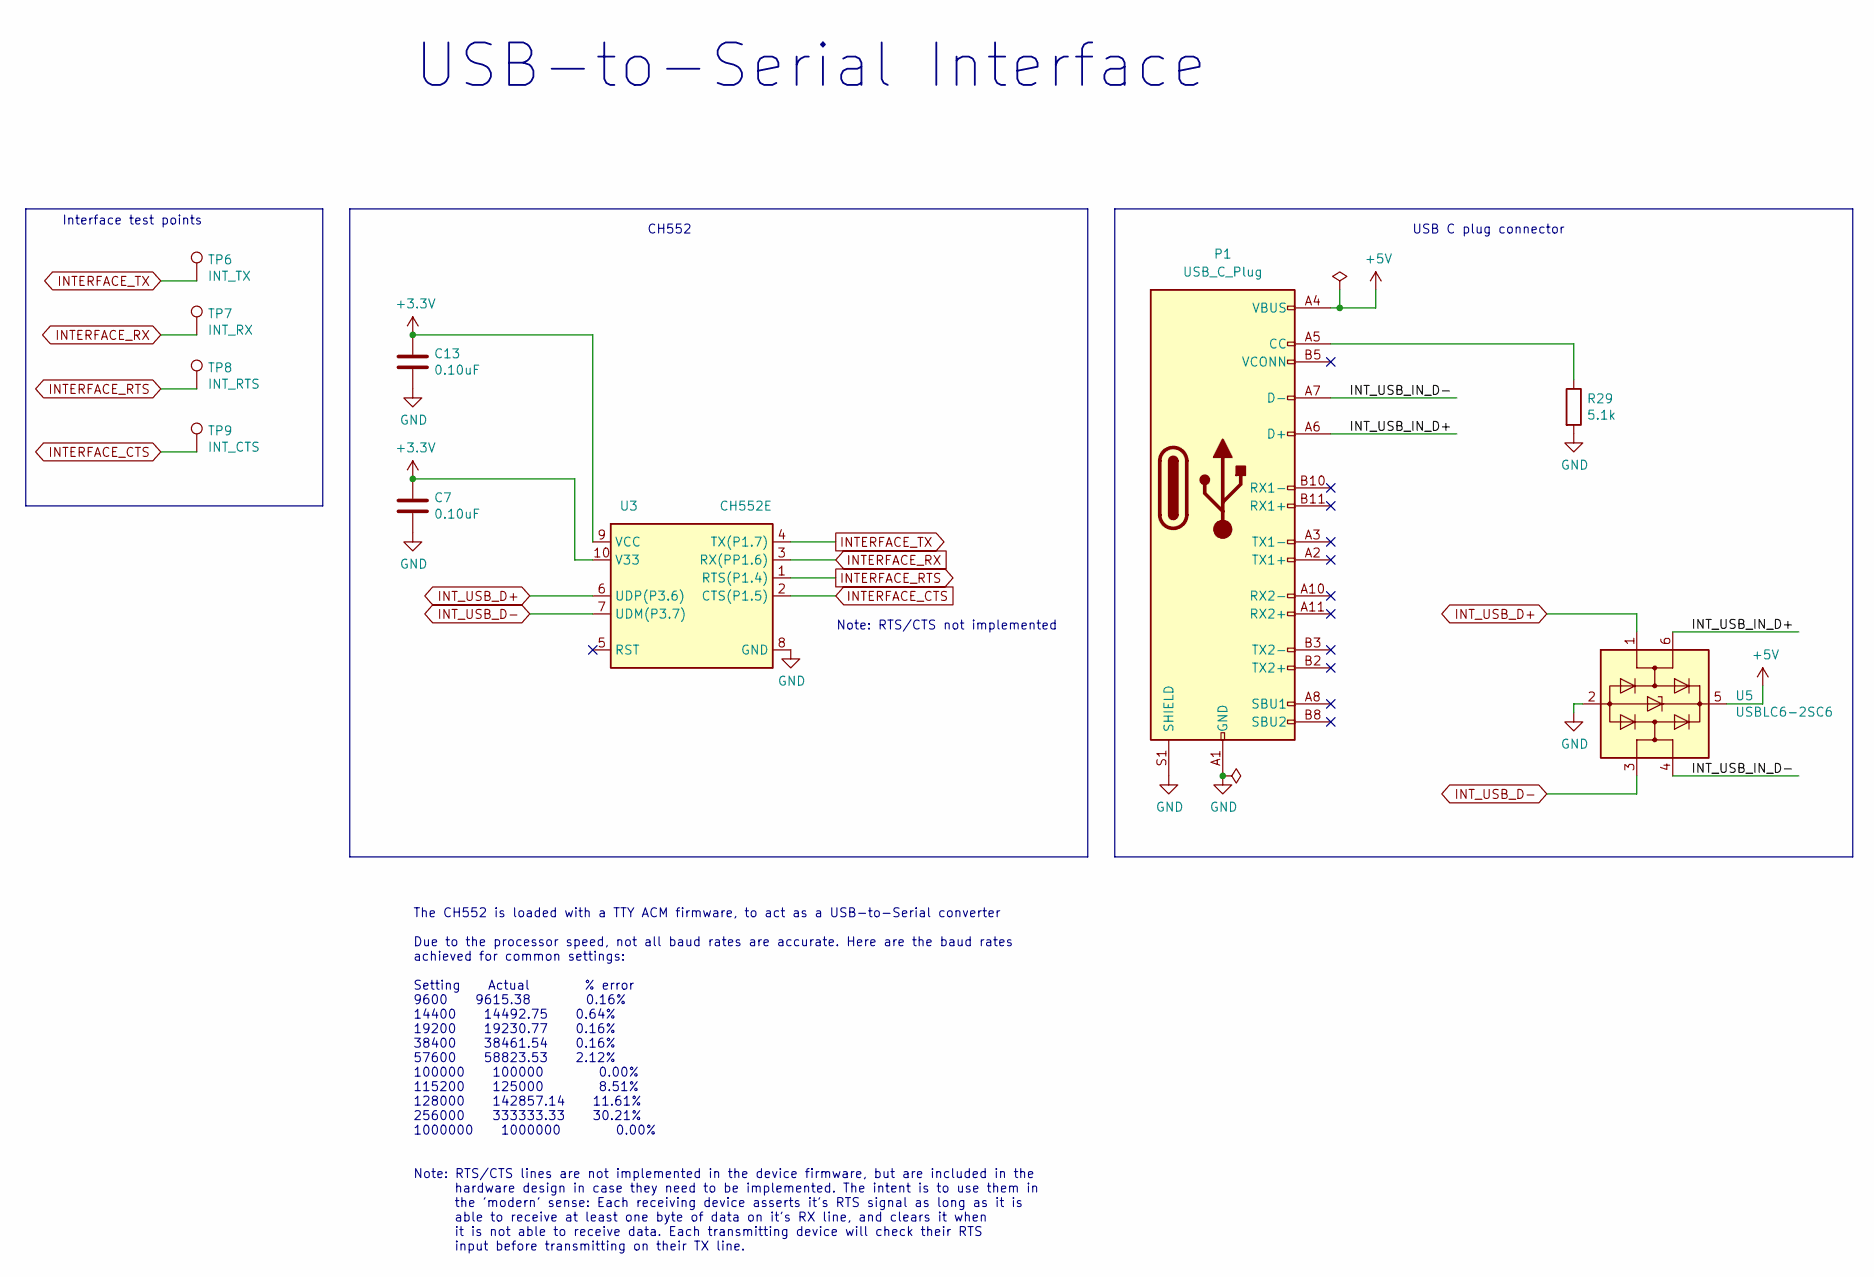
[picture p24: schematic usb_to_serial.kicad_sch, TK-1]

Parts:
C7, C13: 0.10uF; CAPC1005X06L
P1: USB_C_Plug; U261-241N-4BS60; Manufacturer Part Number U261-241N-4BS60
R29: 5.1k; ERJ2G(0402)_L
TP6: INT_TX; TestPoint_Pad_D1.0mm
TP7: INT_RX; TestPoint_Pad_D1.0mm
TP8: INT_RTS; TestPoint_Pad_D1.0mm
TP9: INT_CTS; TestPoint_Pad_D1.0mm
U3: CH552E; MSOP-10_3x3mm_P0.5mm; Manufacturer Part Number CH552E
U5: USBLC6-2SC6; SOT-23-6; Manufacturer Part Number USBLC6-2SC6

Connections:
+3V3: C7.1, C13.1, U3.9 (VCC), U3.10 (V33); also elsewhere on the board
+5V: P1.A4 (VBUS), P1.A9 (VBUS), P1.B4 (VBUS), P1.B9 (VBUS), U5.5 (VBUS); also elsewhere on the board
/USB to Serial converter/INT_USB_IN_D+: P1.A6 (D+), U5.6 (I/O1)
/USB to Serial converter/INT_USB_IN_D-: P1.A7 (D-), U5.4 (I/O2)
GND: C7.2, C13.2, P1.A1 (GND), P1.A12 (GND), P1.B1 (GND), P1.B12 (GND), P1.S1 (SHIELD), R29.2, U3.8 (GND), U5.2 (GND); also elsewhere on the board
INTERFACE_CTS: TP9.1, U3.2 (CTS(P1.5)); also elsewhere on the board
INTERFACE_RTS: TP8.1, U3.1 (RTS(P1.4)); also elsewhere on the board
INTERFACE_RX: TP7.1, U3.3 (RX(PP1.6)); also elsewhere on the board
INTERFACE_TX: TP6.1, U3.4 (TX(P1.7)); also elsewhere on the board
INT_USB_D+: U3.6 (UDP(P3.6)), U5.1 (I/O1)
INT_USB_D-: U3.7 (UDM(P3.7)), U5.3 (I/O2)
unnamed: P1.A5 (CC), R29.1

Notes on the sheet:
USB C plug connector
CH552
USB-to-Serial Interface
The CH552 is loaded with a TTY ACM firmware, to act as a USB-to-Serial converter Due to the processor speed, not all baud rates are accurate. Here are the baud rates achieved for common settings: Setting Actual % error 9600 9615.38 0.16% 14400 14492.75 0.64% 19200 19230.77 0.16% 38400 38461.54 0.16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
Interface test points
Note: RTS/CTS not implemented

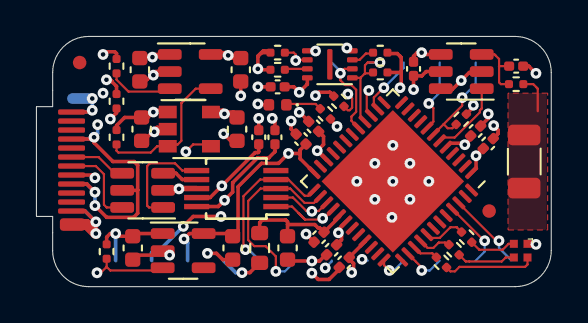
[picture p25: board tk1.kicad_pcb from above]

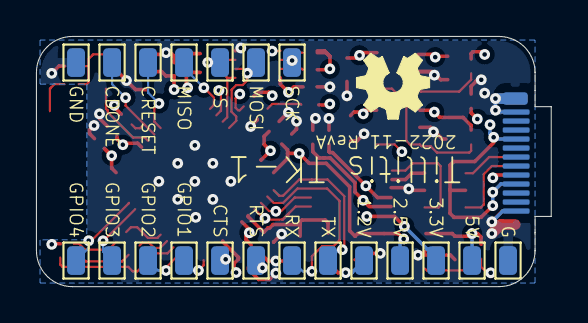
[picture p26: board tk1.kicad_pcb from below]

Board: 4 copper layers, 28.6 x 13.9 mm, 69 parts (20 on the bottom side), 40 nets.

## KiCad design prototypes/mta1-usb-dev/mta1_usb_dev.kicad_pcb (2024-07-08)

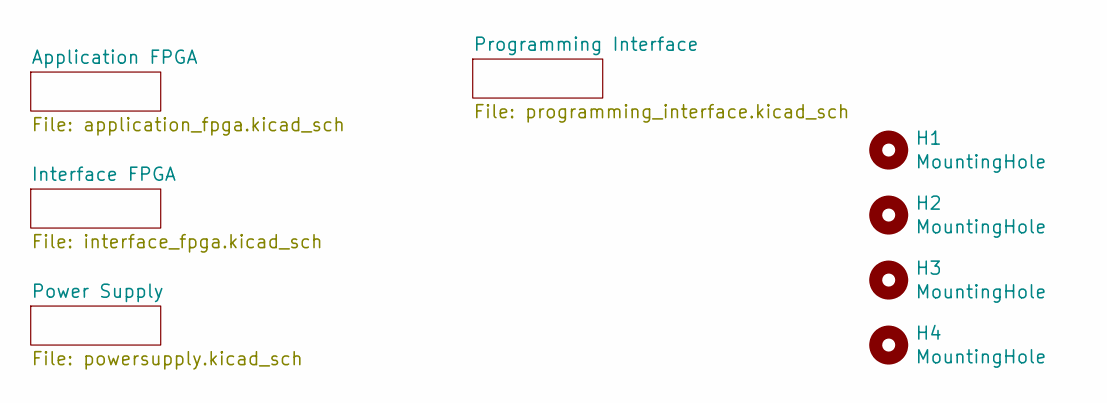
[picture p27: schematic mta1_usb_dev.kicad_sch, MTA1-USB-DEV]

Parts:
H1, H2, H3, H4: MountingHole; MountingHole_3.2mm_M3_DIN965_Pad_TopBottom

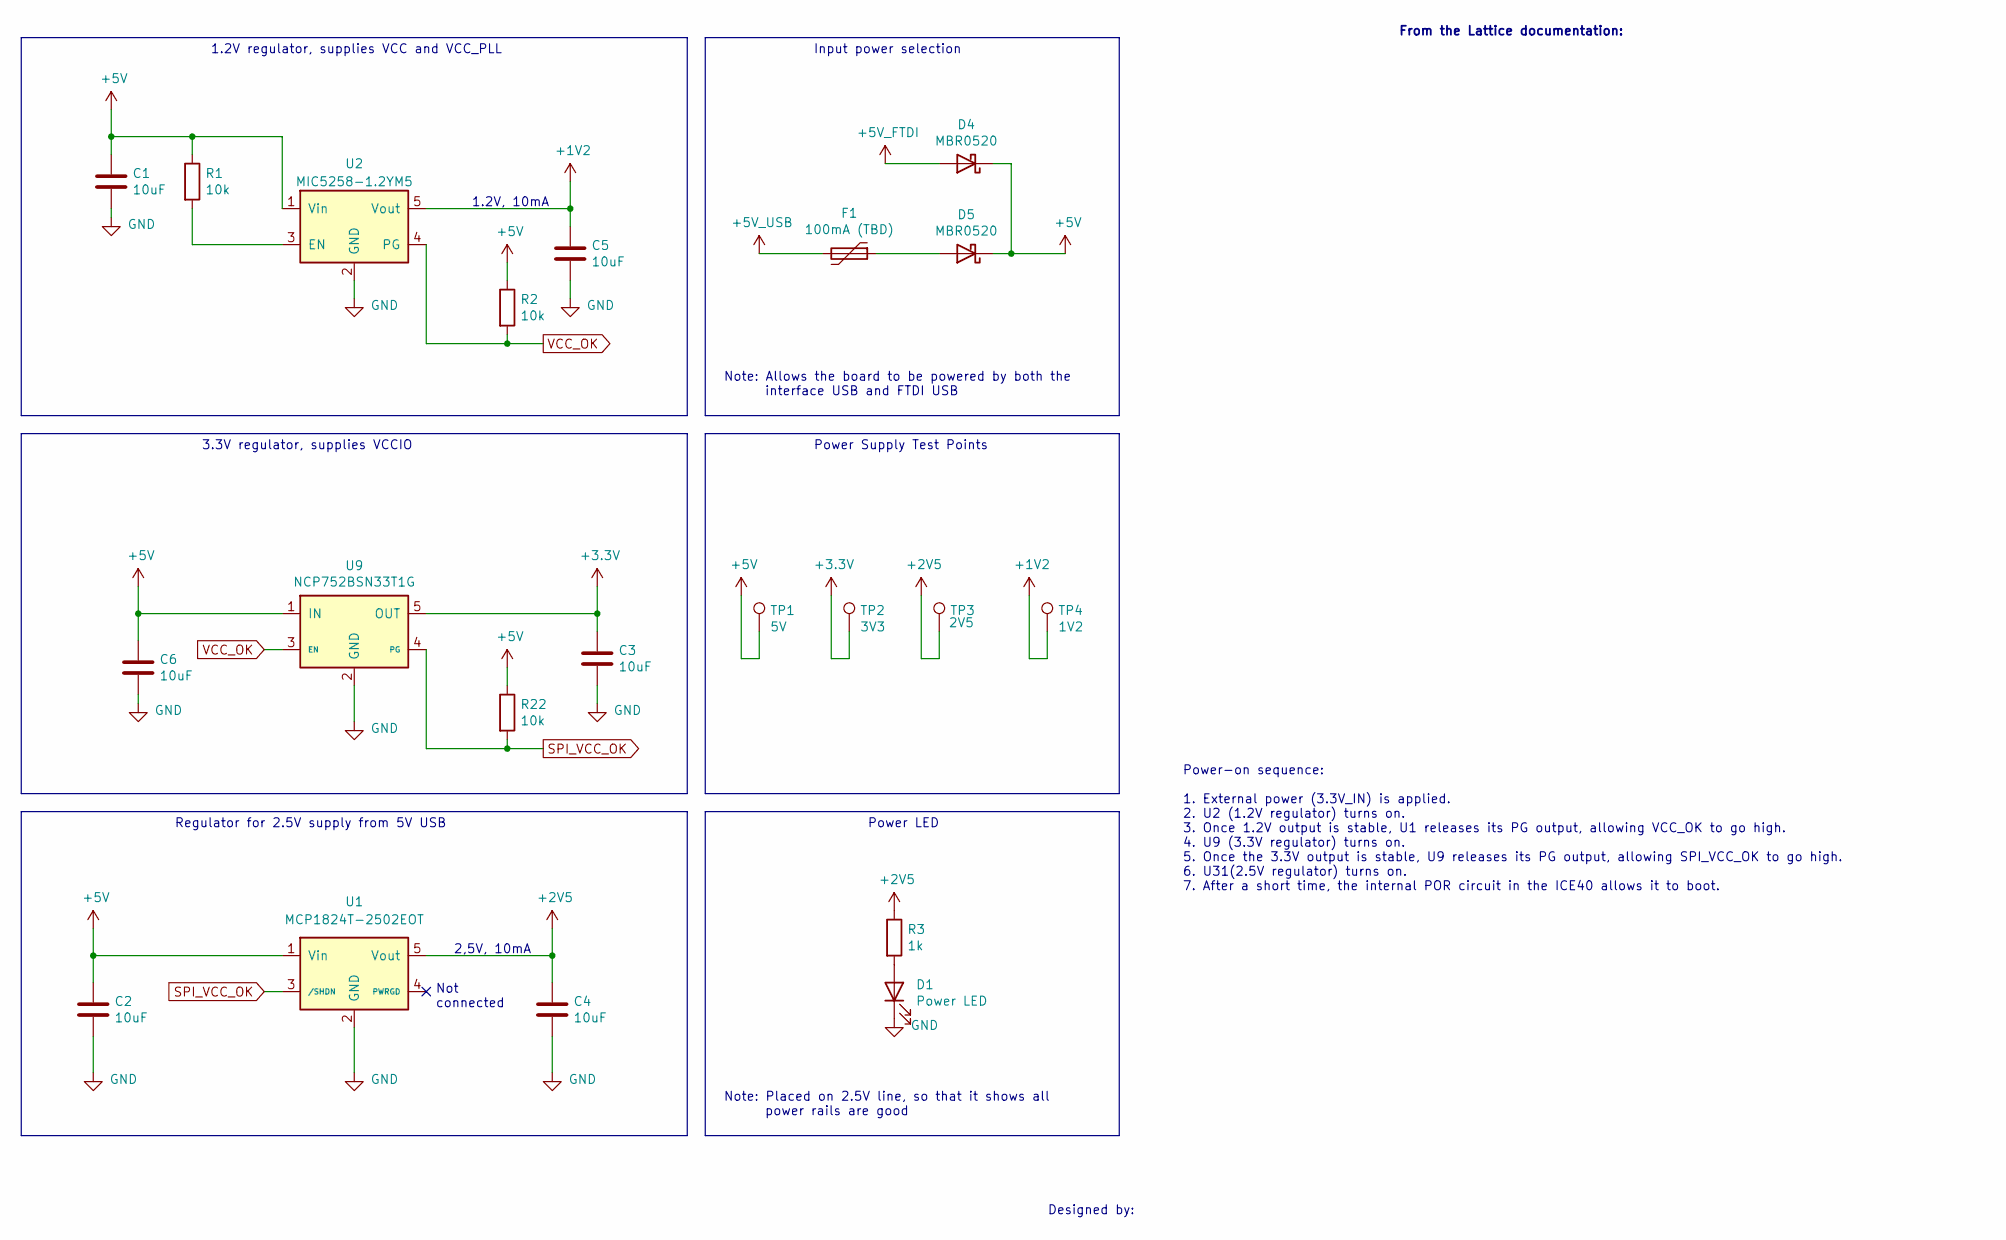
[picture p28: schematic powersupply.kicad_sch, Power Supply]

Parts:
C1, C2, C3, C4, C5, C6: 10uF; CAPC1608X09L
D1: Power LED; LED_0402_1005Metric
D4, D5: MBR0520; D_SOD-123
F1: 100mA (TBD); Fuse_1206_3216Metric
R1, R2, R22: 10k; ERJ2G(0402)_L
R3: 1k; ERJ2G(0402)_L
TP1: 5V; TestPoint_Pad_D1.0mm
TP2: 3V3; TestPoint_Pad_D1.0mm
TP3: 2V5; TestPoint_Pad_D1.0mm
TP4: 1V2; TestPoint_Pad_D1.0mm
U1: MCP1824T-2502EOT; SOT-23-5
U2: MIC5258-1.2YM5; SOT-23-5
U9: NCP752BSN33T1G

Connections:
+1V2: C5.1, TP4.1, U2.5 (Vout); also elsewhere on the board
+2V5: C4.1, R3.1, TP3.1, U1.5 (Vout); also elsewhere on the board
+3V3: C3.1, TP2.1, U9.5 (OUT); also elsewhere on the board
+5V: C1.1, C2.1, C6.1, D4.1 (K), D5.1 (K), R1.1, R2.1, R22.1, TP1.1, U1.1 (Vin), U2.1 (Vin), U9.1 (IN)
+5V_FTDI: D4.2 (A); also elsewhere on the board
+5V_USB: F1.2; also elsewhere on the board
GND: C1.2, C2.2, C3.2, C4.2, C5.2, C6.2, D1.1 (K), U1.2 (GND), U2.2 (GND), U9.2 (GND); also elsewhere on the board
unnamed: D1.2 (A), R3.2
unnamed: D5.2 (A), F1.1
unnamed: R1.2, U2.3 (EN)
SPI_VCC_OK: R22.2, U1.3 (/SHDN), U9.4 (PG)
VCC_OK: R2.2, U2.4 (PG), U9.3 (EN)

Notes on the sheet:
Power-on sequence: 1. External power (3.3V_IN) is applied. 2. U2 (1.2V regulator) turns on. 3. Once 1.2V output is stable, U1 releases its PG output, allowing VCC_OK to go high. 4. U9 (3.3V regulator) turns on. 5. Once the 3.3V output is stable, U9 releases its PG output, allowing SPI_VCC_OK to go 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
Note: Allows the board to be powered by both the interface USB and FTDI USB
2,5V, 10mA
Note: Placed on 2.5V line, so that it shows all power rails are good
Designed by:
Input power selection
1.2V, 10mA
From the Lattice documentation:
1.2V regulator, supplies VCC and VCC_PLL
3.3V regulator, supplies VCCIO
Not connected
Power Supply Test Points
Power LED
Regulator for 2.5V supply from 5V USB

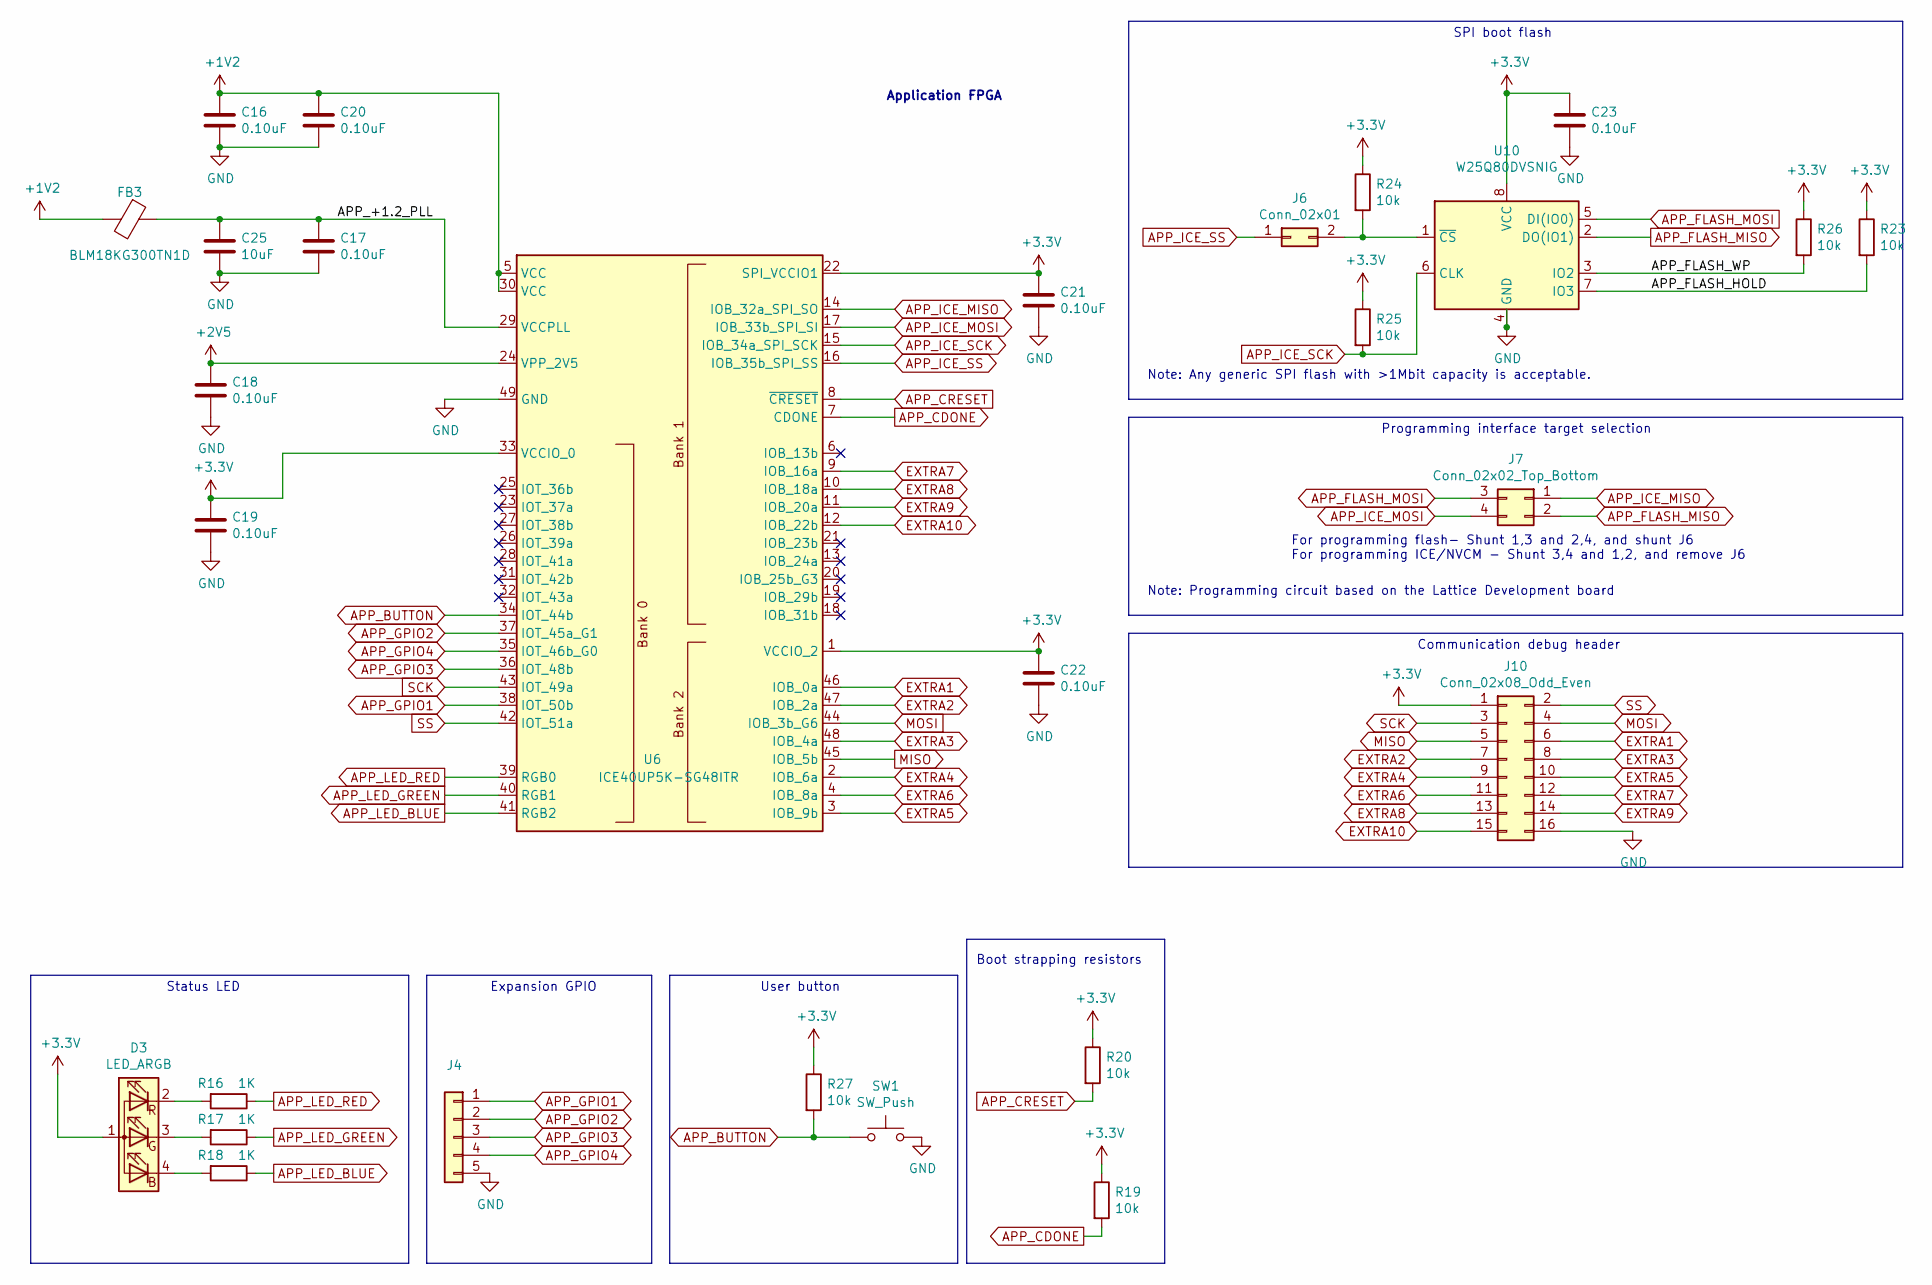
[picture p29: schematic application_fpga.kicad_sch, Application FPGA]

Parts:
C16, C17, C18, C19, C20, C21, C22, C23: 0.10uF; CAPC1005X06L
C25: 10uF; CAPC1608X09L
D3: LED_ARGB; 0402rgb-1010
FB3: BLM18KG300TN1D; Ferritbead_0603_1608Metric
J4: PinHeader_1x05_P2.54mm_Vertical
J6: Conn_02x01; PinHeader_1x02_P2.54mm_Vertical
J7: Conn_02x02_Top_Bottom; PinHeader_2x02_P2.54mm_Vertical
J10: Conn_02x08_Odd_Even; PinHeader_2x08_P2.54mm_Vertical
R16, R17, R18: 1K; ERJ2G(0402)_L
R19, R20, R23, R24, R25, R26, R27: 10k; ERJ2G(0402)_L
SW1: SW_Push; SW_Push_SPST_NO_Alps_SKRK
U6: ICE40UP5K-SG48ITR; QFN-48-1EP_7x7mm_P0.5mm_EP5.6x5.6mm
U10: W25Q80DVSNIG; SOIC-8_3.9x4.9mm_P1.27mm

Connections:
+1V2: C16.1, C20.1, FB3.2, U6.5 (VCC), U6.30 (VCC); also elsewhere on the board
+2V5: C18.1, U6.24 (VPP_2V5); also elsewhere on the board
+3V3: C19.1, C21.1, C22.1, C23.1, D3.1 (A), J10.1, R19.1, R20.1, R23.1, R24.1, R25.1, R26.1, R27.1, U6.1 (VCCIO_2), U6.22 (SPI_VCCIO1), U6.33 (VCCIO_0), U10.8 (VCC); also elsewhere on the board
/Application FPGA/APP_+1.2_PLL: C17.1, C25.1, FB3.1, U6.29 (VCCPLL)
/Application FPGA/APP_FLASH_HOLD: R23.2, U10.7 (IO3)
/Application FPGA/APP_FLASH_WP: R26.2, U10.3 (IO2)
APP_BUTTON: R27.2, SW1.1, U6.34 (IOT_44b)
APP_CDONE: R19.2, U6.7 (CDONE); also elsewhere on the board
APP_CRESET: R20.2, U6.8 (~CRESET); also elsewhere on the board
APP_FLASH_MISO: J7.2, U10.2 (DO(IO1)); also elsewhere on the board
APP_FLASH_MOSI: J7.3, U10.5 (DI(IO0)); also elsewhere on the board
APP_GPIO1: J4.1, U6.38 (IOT_50b)
APP_GPIO2: J4.2, U6.37 (IOT_45a_G1)
APP_GPIO3: J4.3, U6.36 (IOT_48b)
APP_GPIO4: J4.4, U6.35 (IOT_46b_G0)
APP_ICE_MISO: J7.1, U6.14 (IOB_32a_SPI_SO)
APP_ICE_MOSI: J7.4, U6.17 (IOB_33b_SPI_SI)
APP_ICE_SCK: R25.2, U6.15 (IOB_34a_SPI_SCK), U10.6 (CLK); also elsewhere on the board
APP_ICE_SS: J6.1, U6.16 (IOB_35b_SPI_SS); also elsewhere on the board
APP_LED_BLUE: R18.1, U6.41 (RGB2)
APP_LED_GREEN: R17.1, U6.40 (RGB1)
APP_LED_RED: R16.1, U6.39 (RGB0)
EXTRA1: J10.6, U6.46 (IOB_0a); also elsewhere on the board
EXTRA2: J10.7, U6.47 (IOB_2a); also elsewhere on the board
EXTRA3: J10.8, U6.48 (IOB_4a); also elsewhere on the board
EXTRA4: J10.9, U6.2 (IOB_6a); also elsewhere on the board
EXTRA5: J10.10, U6.3 (IOB_9b); also elsewhere on the board
EXTRA6: J10.11, U6.4 (IOB_8a); also elsewhere on the board
EXTRA7: J10.12, U6.9 (IOB_16a); also elsewhere on the board
EXTRA8: J10.13, U6.10 (IOB_18a); also elsewhere on the board
EXTRA9: J10.14, U6.11 (IOB_20a); also elsewhere on the board
EXTRA10: J10.15, U6.12 (IOB_22b); also elsewhere on the board
GND: C16.2, C17.2, C18.2, C19.2, C20.2, C21.2, C22.2, C23.2, C25.2, J4.5, J10.16, SW1.2, U6.49 (GND), U10.4 (GND); also elsewhere on the board
MISO: J10.5, U6.45 (IOB_5b); also elsewhere on the board
MOSI: J10.4, U6.44 (IOB_3b_G6); also elsewhere on the board
unnamed: D3.2 (RK), R16.2
unnamed: D3.3 (GK), R17.2
unnamed: D3.4 (BK), R18.2
unnamed: J6.2, R24.2, U10.1 (~CS)
SCK: J10.3, U6.43 (IOT_49a); also elsewhere on the board
SS: J10.2, U6.42 (IOT_51a); also elsewhere on the board

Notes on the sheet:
Application FPGA
Status LED
Expansion GPIO
Programming interface target selection
SPI boot flash
User button
For programming flash- Shunt 1,3 and 2,4, and shunt J6 For programming ICE/NVCM - Shunt 3,4 and 1,2, and remove J6
Note: Any generic SPI flash with >1Mbit capacity is acceptable.
Communication debug header
Note: Programming circuit based on the Lattice Development board
Boot strapping resistors

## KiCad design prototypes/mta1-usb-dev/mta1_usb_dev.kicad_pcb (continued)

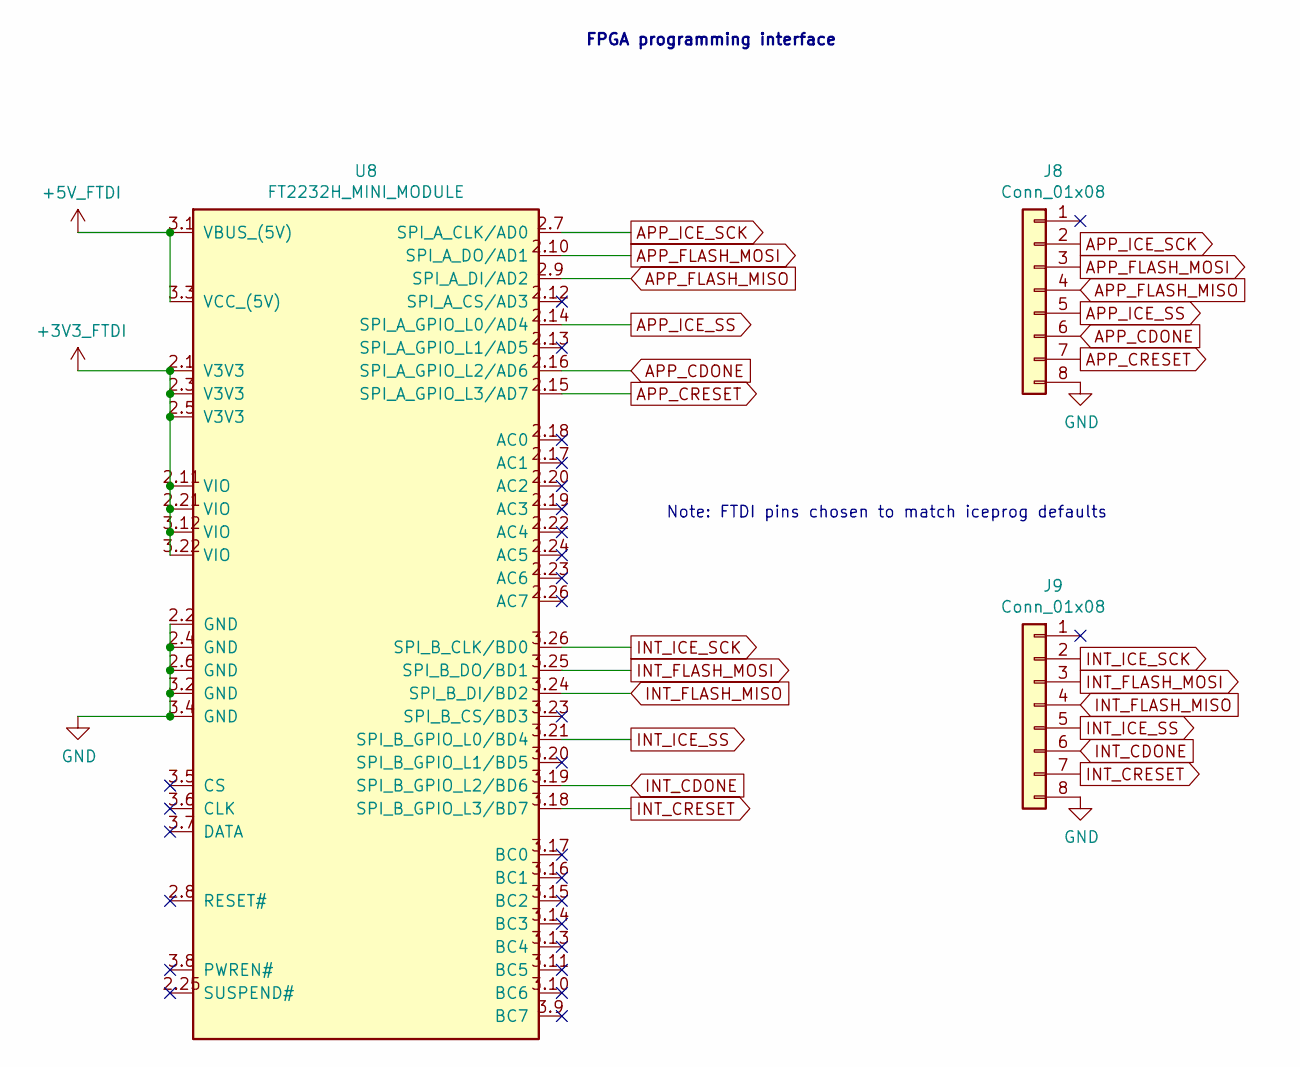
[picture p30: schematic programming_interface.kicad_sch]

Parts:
J8, J9: Conn_01x08; PinHeader_1x08_P2.54mm_Vertical
U8: FT2232H_MINI_MODULE

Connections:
+3V3_FTDI: U8.2.1 (V3V3), U8.2.3 (V3V3), U8.2.5 (V3V3), U8.2.11 (VIO), U8.2.21 (VIO), U8.3.12 (VIO), U8.3.22 (VIO)
+5V_FTDI: U8.3.1 (VBUS_(5V)), U8.3.3 (VCC_(5V)); also elsewhere on the board
APP_CDONE: J8.6, U8.2.16 (SPI_A_GPIO_L2/AD6); also elsewhere on the board
APP_CRESET: J8.7, U8.2.15 (SPI_A_GPIO_L3/AD7); also elsewhere on the board
APP_FLASH_MISO: J8.4, U8.2.9 (SPI_A_DI/AD2); also elsewhere on the board
APP_FLASH_MOSI: J8.3, U8.2.10 (SPI_A_DO/AD1); also elsewhere on the board
APP_ICE_SCK: J8.2, U8.2.7 (SPI_A_CLK/AD0); also elsewhere on the board
APP_ICE_SS: J8.5, U8.2.14 (SPI_A_GPIO_L0/AD4); also elsewhere on the board
GND: J8.8, J9.8, U8.2.2 (GND), U8.2.4 (GND), U8.2.6 (GND), U8.3.2 (GND), U8.3.4 (GND); also elsewhere on the board
INT_CDONE: J9.6, U8.3.19 (SPI_B_GPIO_L2/BD6); also elsewhere on the board
INT_CRESET: J9.7, U8.3.18 (SPI_B_GPIO_L3/BD7); also elsewhere on the board
INT_FLASH_MISO: J9.4, U8.3.24 (SPI_B_DI/BD2); also elsewhere on the board
INT_FLASH_MOSI: J9.3, U8.3.25 (SPI_B_DO/BD1); also elsewhere on the board
INT_ICE_SCK: J9.2, U8.3.26 (SPI_B_CLK/BD0); also elsewhere on the board
INT_ICE_SS: J9.5, U8.3.21 (SPI_B_GPIO_L0/BD4); also elsewhere on the board

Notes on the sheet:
Note: FTDI pins chosen to match iceprog defaults
FPGA programming interface

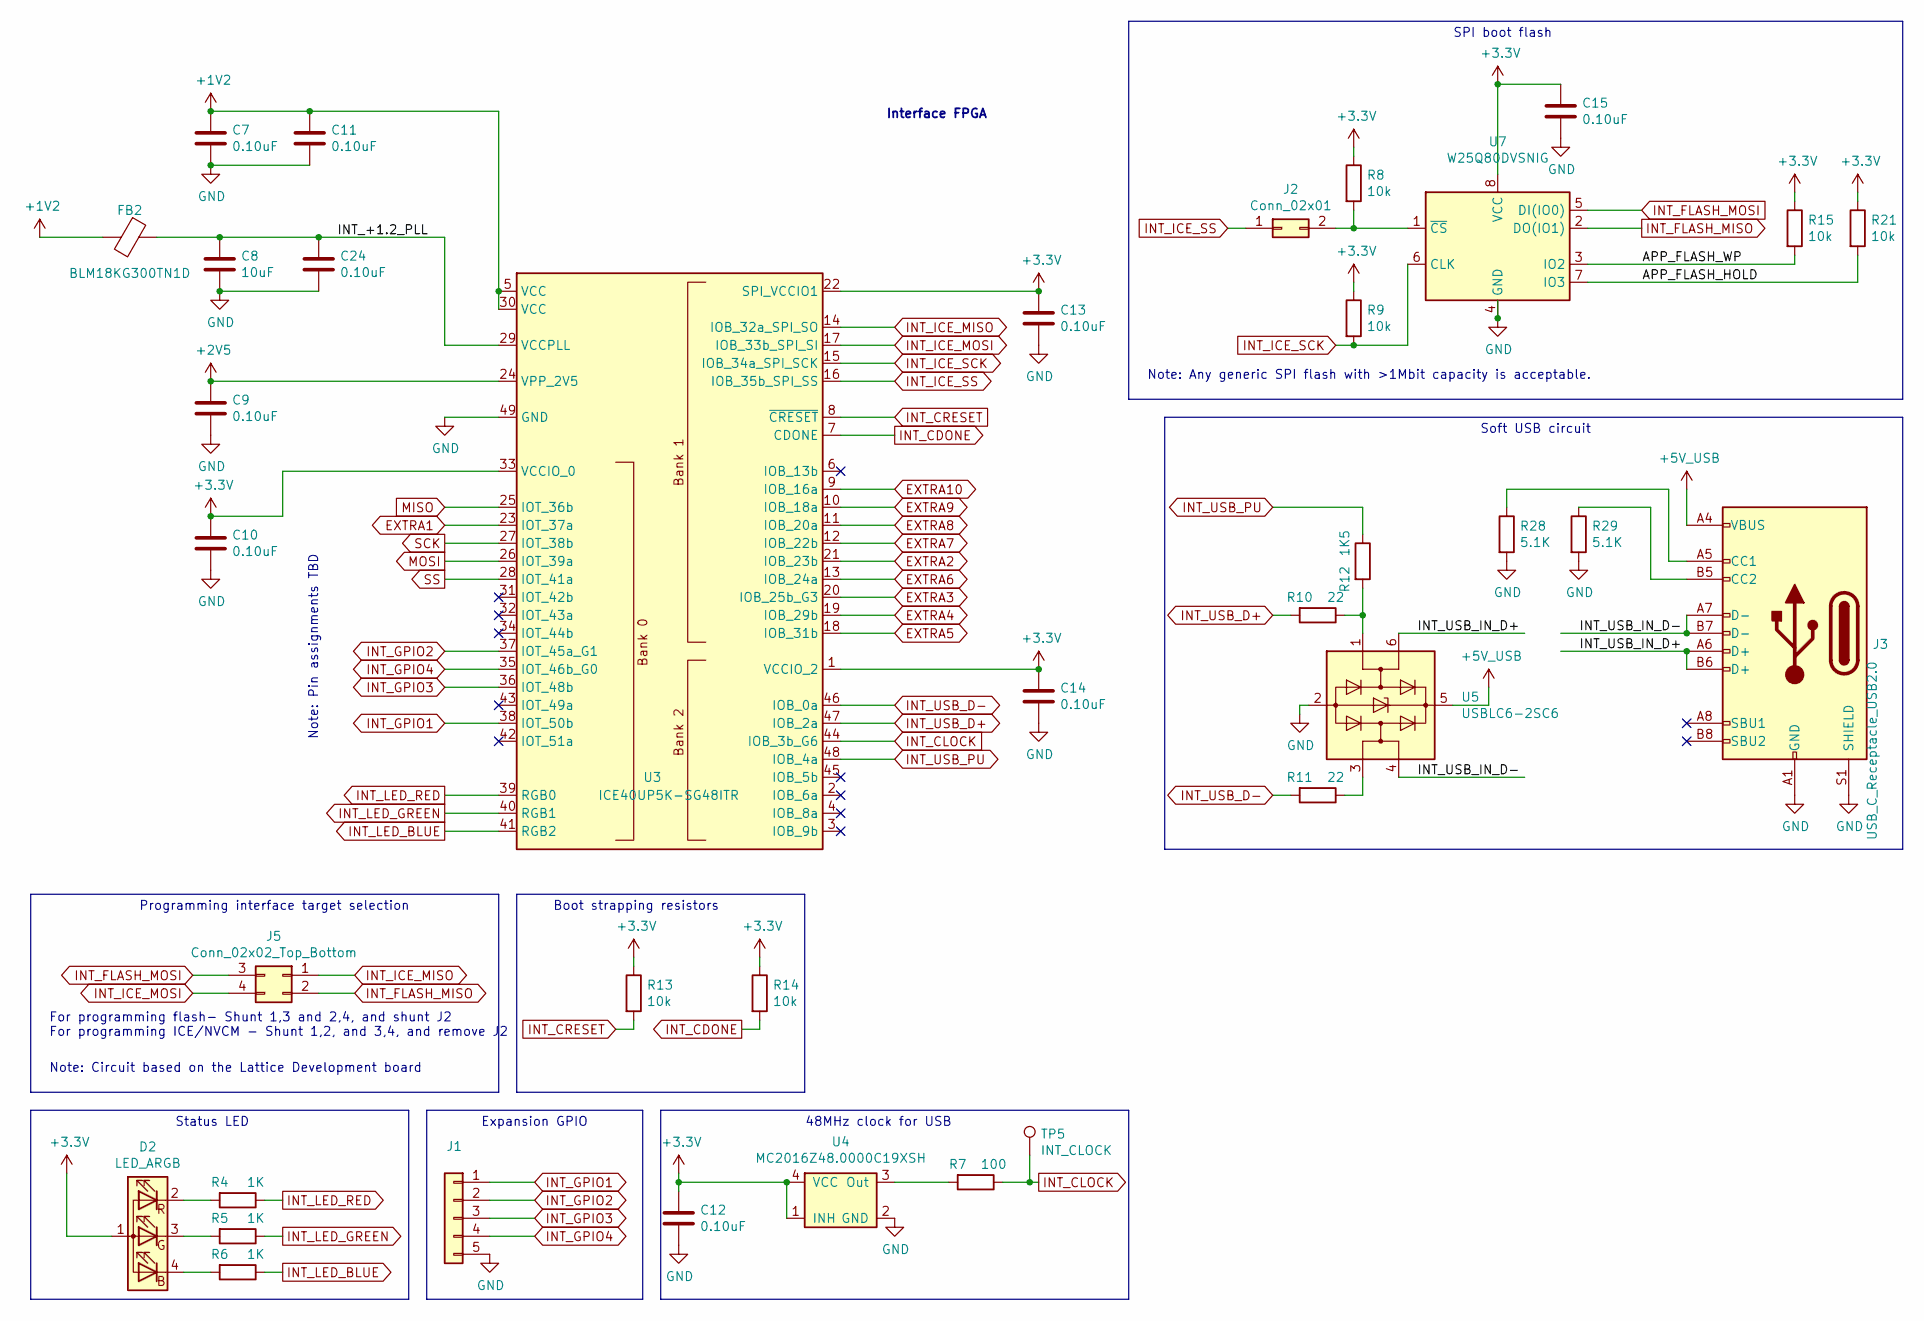
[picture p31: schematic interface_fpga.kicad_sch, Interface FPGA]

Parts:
C7, C9, C10, C11, C12, C13, C14, C15, C24: 0.10uF; CAPC1005X06L
C8: 10uF; CAPC1608X09L
D2: LED_ARGB; 0402rgb-1010
FB2: BLM18KG300TN1D; Ferritbead_0603_1608Metric
J1: PinHeader_1x05_P2.54mm_Vertical
J2: Conn_02x01; PinHeader_1x02_P2.54mm_Vertical
J3: USB_C_Receptacle_USB2.0; USB_C_Receptacle_HRO_TYPE-C-31-M-12
J5: Conn_02x02_Top_Bottom; PinHeader_2x02_P2.54mm_Vertical
R4, R5, R6: 1K; ERJ2G(0402)_L
R7: 100; ERJ2G(0402)_L
R8, R9, R13, R14, R15, R21: 10k; ERJ2G(0402)_L
R10, R11: 22; ERJ2G(0402)_L
R12: 1K5; ERJ2G(0402)_L
R28, R29: 5.1K; ERJ2G(0402)_L
TP5: INT_CLOCK; TestPoint_Pad_D1.0mm
U3: ICE40UP5K-SG48ITR; QFN-48-1EP_7x7mm_P0.5mm_EP5.6x5.6mm
U4: MC2016Z48.0000C19XSH; MC2016Z
U5: USBLC6-2SC6; SOT-23-6
U7: W25Q80DVSNIG; SOIC-8_3.9x4.9mm_P1.27mm

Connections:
+1V2: C7.1, C11.1, FB2.2, U3.5 (VCC), U3.30 (VCC); also elsewhere on the board
+2V5: C9.1, U3.24 (VPP_2V5); also elsewhere on the board
+3V3: C10.1, C12.1, C13.1, C14.1, C15.1, D2.1 (A), R8.1, R9.1, R13.1, R14.1, R15.1, R21.1, U3.1 (VCCIO_2), U3.22 (SPI_VCCIO1), U3.33 (VCCIO_0), U4.1 (INH), U4.4 (VCC), U7.8 (VCC); also elsewhere on the board
+5V_USB: J3.A4 (VBUS), J3.A9 (VBUS), J3.B4 (VBUS), J3.B9 (VBUS), U5.5 (VBUS); also elsewhere on the board
/Interface FPGA/APP_FLASH_HOLD: R21.2, U7.7 (IO3)
/Interface FPGA/APP_FLASH_WP: R15.2, U7.3 (IO2)
/Interface FPGA/INT_+1.2_PLL: C8.1, C24.1, FB2.1, U3.29 (VCCPLL)
/Interface FPGA/INT_USB_IN_D+: J3.A6 (D+), J3.B6 (D+), U5.6 (I/O1)
/Interface FPGA/INT_USB_IN_D-: J3.A7 (D-), J3.B7 (D-), U5.4 (I/O2)
EXTRA1: U3.23 (IOT_37a); also elsewhere on the board
EXTRA2: U3.21 (IOB_23b); also elsewhere on the board
EXTRA3: U3.20 (IOB_25b_G3); also elsewhere on the board
EXTRA4: U3.19 (IOB_29b); also elsewhere on the board
EXTRA5: U3.18 (IOB_31b); also elsewhere on the board
EXTRA6: U3.13 (IOB_24a); also elsewhere on the board
EXTRA7: U3.12 (IOB_22b); also elsewhere on the board
EXTRA8: U3.11 (IOB_20a); also elsewhere on the board
EXTRA9: U3.10 (IOB_18a); also elsewhere on the board
EXTRA10: U3.9 (IOB_16a); also elsewhere on the board
GND: C7.2, C8.2, C9.2, C10.2, C11.2, C12.2, C13.2, C14.2, C15.2, C24.2, J1.5, J3.A1 (GND), J3.A12 (GND), J3.B1 (GND), J3.B12 (GND), J3.S1 (SHIELD), R28.2, R29.2, U3.49 (GND), U4.2 (GND), U5.2 (GND), U7.4 (GND); also elsewhere on the board
INT_CDONE: R14.2, U3.7 (CDONE); also elsewhere on the board
INT_CLOCK: R7.1, TP5.1, U3.44 (IOB_3b_G6)
INT_CRESET: R13.2, U3.8 (~CRESET); also elsewhere on the board
INT_FLASH_MISO: J5.2, U7.2 (DO(IO1)); also elsewhere on the board
INT_FLASH_MOSI: J5.3, U7.5 (DI(IO0)); also elsewhere on the board
INT_GPIO1: J1.1, U3.38 (IOT_50b)
INT_GPIO2: J1.2, U3.37 (IOT_45a_G1)
INT_GPIO3: J1.3, U3.36 (IOT_48b)
INT_GPIO4: J1.4, U3.35 (IOT_46b_G0)
INT_ICE_MISO: J5.1, U3.14 (IOB_32a_SPI_SO)
INT_ICE_MOSI: J5.4, U3.17 (IOB_33b_SPI_SI)
INT_ICE_SCK: R9.2, U3.15 (IOB_34a_SPI_SCK), U7.6 (CLK); also elsewhere on the board
INT_ICE_SS: J2.1, U3.16 (IOB_35b_SPI_SS); also elsewhere on the board
INT_LED_BLUE: R6.1, U3.41 (RGB2)
INT_LED_GREEN: R5.1, U3.40 (RGB1)
INT_LED_RED: R4.1, U3.39 (RGB0)
INT_USB_D+: R10.2, U3.47 (IOB_2a)
INT_USB_D-: R11.2, U3.46 (IOB_0a)
INT_USB_PU: R12.1, U3.48 (IOB_4a)
MISO: U3.25 (IOT_36b); also elsewhere on the board
MOSI: U3.26 (IOT_39a); also elsewhere on the board
unnamed: D2.2 (RK), R4.2
unnamed: D2.3 (GK), R5.2
unnamed: D2.4 (BK), R6.2
unnamed: J2.2, R8.2, U7.1 (~CS)
unnamed: J3.A5 (CC1), R28.1
unnamed: J3.B5 (CC2), R29.1
unnamed: R7.2, U4.3 (Out)
unnamed: R10.1, R12.2, U5.1 (I/O1)
unnamed: R11.1, U5.3 (I/O2)
SCK: U3.27 (IOT_38b); also elsewhere on the board
SS: U3.28 (IOT_41a); also elsewhere on the board

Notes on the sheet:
Expansion GPIO
48MHz clock for USB
Note: Any generic SPI flash with >1Mbit capacity is acceptable.
Boot strapping resistors
Soft USB circuit
Note: Circuit based on the Lattice Development board
Status LED
Programming interface target selection
Interface FPGA
Note: Pin assignments TBD
For programming flash- Shunt 1,3 and 2,4, and shunt J2 For programming ICE/NVCM - Shunt 1,2, and 3,4, and remove J2
SPI boot flash

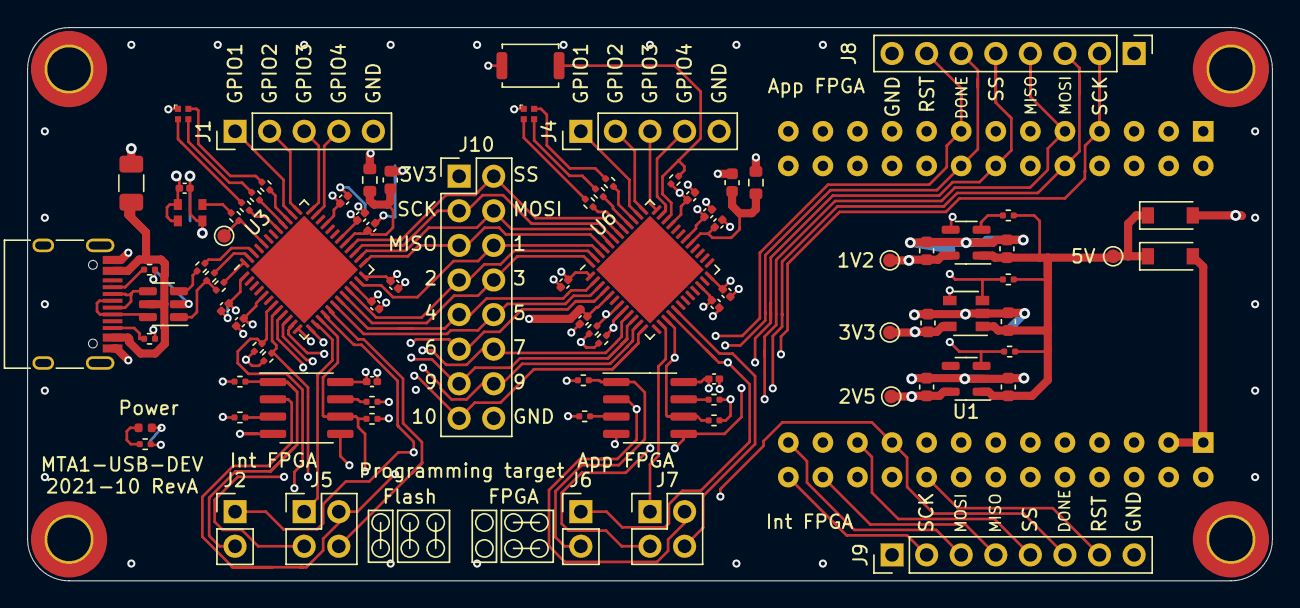
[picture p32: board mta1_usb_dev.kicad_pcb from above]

Board: 4 copper layers, 91.4 x 40.6 mm, 92 parts (0 on the bottom side), 83 nets.

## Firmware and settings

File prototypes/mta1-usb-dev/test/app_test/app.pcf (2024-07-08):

# Host Communication
set_io HOST_SS      42
set_io HOST_SCK     43
set_io HOST_MOSI    44
set_io HOST_MISO    45

set_io HOST_EXTRA1  46
set_io HOST_EXTRA2  47
set_io HOST_EXTRA3  48
set_io HOST_EXTRA4  2
set_io HOST_EXTRA5  3
set_io HOST_EXTRA6  4
set_io HOST_EXTRA7  9
set_io HOST_EXTRA8  10
set_io HOST_EXTRA9  11
set_io HOST_EXTRA10 12

# Expansion
set_io APP_GPIO1    38
set_io APP_GPIO2    37
set_io APP_GPIO3    36
set_io APP_GPIO4    35

## User IO
set_io APP_BUTTON   34

set_io RGB0         39
set_io RGB1         40
set_io RGB2         41

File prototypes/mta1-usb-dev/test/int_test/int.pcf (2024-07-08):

# Host Communication
set_io HOST_SS      28
set_io HOST_SCK     27
set_io HOST_MOSI    26
set_io HOST_MISO    25

set_io HOST_EXTRA1  23
set_io HOST_EXTRA2  21
set_io HOST_EXTRA3  20
set_io HOST_EXTRA4  19
set_io HOST_EXTRA5  18
set_io HOST_EXTRA6  13
set_io HOST_EXTRA7  12
set_io HOST_EXTRA8  11
set_io HOST_EXTRA9  10
set_io HOST_EXTRA10 9

# USB
#set_io INT_USB_D-   46
#set_io INT_USB_D+   47
#set_io INT_USB_PU   48

set_io INT_CLOCK    44

# Expansion
set_io INT_GPIO1    38
set_io INT_GPIO2    37
set_io INT_GPIO3    36
set_io INT_GPIO4    35

## User IO
set_io RGB0         39
set_io RGB1         40
set_io RGB2         41

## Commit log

2024-07-08 Make initial public release
    [2022-08-22 case production bottom.step, 2022-08-22 case production top.step, 2022-08-22 case v3.f3z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]
2024-07-08 Make hid_test fail less confusingly when programming device is not connected
    Add requirements.txt
2024-07-08 Add (hardware) production tests for the TK-1 and TP-1 (#69)
    * ch552 firmware: add ch55x support files directly
    * Add sdcc compiler to docker image, for building CH552 firmware
    * Rework production test script
    * Add menu-based test runner
    * Rewrite production test flows as lists of individual tests
    * Add both production flows and manual tests to menu
    * Switch to using included binaries
    * production test: Update message format
    * test_txrx_touchpad: Retry if device communications fail
    * production test: put all binaries in binaries/ folder
    * binaries/top.bin: replace broken binary
    * flash_check: Check for explicit flash IDs
    * Document most test procedures
    * Test plan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
    [usb_pins-good.csv, usb_pins.csv]
2024-07-08 TK-1 and TP-1 PCBs (#52)
    * Add kicad library for flat programming clip
    * Add descriptions to part symbols
    * Add extended values, manufacturer/distributor info to components in mta1
    * Add new board entry for TK1
    * Add TP1 programmer design
    * Update MTA1-USB-V1 release files to match production
    * Change SPI flash memory type to XT25F08BDFIGT-S
    * Change touch sensor feedback cap to 1uF
    * Add manufacturer, manufacturer part number, distributor, distributor part number
    * Update component values for TK1 PCB
    * Use specific part # for C8
    * Change flash back to Winbond part, for easier sourcing
    * Change C1 to 1pF
    * Fixes for production programmer PCB
    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
    [application_fpga.kicad_sch, powersupply.kicad_sch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]
2024-07-08 Add tk1 case plastic designs
    [case_bottom_revc.step, case_top_revc.step]
2024-07-08 Replaced Cap w. spring contacts
    Updated BOM to improve touch consistency, using a component that springs
    against the plastic case.
    [application_fpga.kicad_sch, powersupply.kicad_sch, tk1.csv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]
2024-07-08 pdf printed
2024-07-08 USB: move firmware for usb-to-serial MCU (CH552)
    Change links to the new ch552_fw directory.
    [baud rate calculator.ods]
2024-07-08 Add injection molded plastic case
    [7927_201_RevE_Case Bottom.STEP, 7927_202_RevE_Case Top.STEP, case_bottom_revc.step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]
2024-09-05 Moved and filtered commits and files from tillitis/tillitis-key1
    The filtering removes all files and commits that are not related to the
    tk1 hardware. This is done using `git-filter-repo`. To replicate the
    results here, checkout commit `354aecb` in tillitis/tillitis-key1 and
    run `git-filter-repo --path hw/boards/mta1-library --path
    hw/boards/mta1-usb-dev --path hw/boards/mta1-usb-v1 --path
    hw/boards/tk1`.
    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
2024-09-05 Move mta1-usb-v1 and mta-usb-dev to prototypes/
    [2022-08-22 case production bottom.step, 2022-08-22 case production top.step, 2022-08-22 case v3.f3z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]
2024-09-05 Move tk1 directly under hw/
    - Move libraries to `hw/lib/`
    - Remove license under hw, it is placed in project's root dir
    [7927_201_RevE_Case Bottom.STEP, 7927_202_RevE_Case Top.STEP, application_fpga.kicad_sch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]
2024-09-05 Update project links to library
    - Symbols
    - Footprints
    - Draw sheet
    [application_fpga.kicad_sch, powersupply.kicad_sch, tk1.kicad_pcb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]
2024-09-05 Fix all ERC errors
    - Update symbols
    - Add PWR_FLAG
    - Disable error on SPICE models
    [application_fpga.kicad_sch, powersupply.kicad_sch, usb_to_serial.kicad_sch]
2024-09-05 Fix some DRC issues
    - Updated footprints to same as libary
    - Updated 3D models in library
    [tk1.kicad_pcb]
2024-09-05 Temporarily filter errors in KiBot to make design build
    All these errors should be fixed in the design
    Filtering:
    - all silk_edge_clearance
    - all silk_overlap
    - clearance violation specifically for two errors; vias
    INTERFACE_RTS/INTERFACE_CTS and +3V3/+2V5
    - all courtyard_overlap
    - one lib_footprint_mismatch for C8
2024-09-05 Do not include open hardware logo in BOM
    [tk1.kicad_pcb]
2024-09-05 Update 3D model links
    - RGB led
    - Ferrite bead
    [tk1.kicad_pcb]
2024-09-05 Change 3D model for FPGA to render properly in KiBot
    - 3D model used does not exist upstreams anymore.
    - Temporarily add filter in kibot config to prevent build error, this
    should be fixed in design.
    [tk1.kicad_pcb]
2024-09-05 Remove generated files from hw/.
    - Harder to keep a consistent version control and guarantee that the
    generated files are up to date.
    - These files can be generated in CI or locally for any commit.
    [tk1-B_Cu.gbr, tk1-B_Mask.gbr, tk1-B_Paste.gbr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]
2024-09-20 Add pictures and some history for the prototypes
    Fix typos in readme
